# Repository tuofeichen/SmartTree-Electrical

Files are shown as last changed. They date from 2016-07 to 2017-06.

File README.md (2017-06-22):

# SmartTree Electrical System Design 
This repo contains the PCB design and Arduino code for the SmartTree electrical system. As a part of Engineers for a Sustainable World (ESW) at Northwestern, SmartTree is a student-run design project aimed to bring solar energy to Northwestern and get the community involved in sustainability. SmartTree provides a ‘trunk’ of solar-powered AC and USB outlets centered around a seating area, so anyone can bring his or her laptop or phone outside without having to worry about running low on battery. Having SmartTree on campus will not only allow students to best utilize technology outdoors, but also raise awareness for the potential solutions clean energy can bring to everyday life. Learn more about [ESW @ NU](http://www.eswnu.org/). 

The repo's directory is briefly described as below:

### Construction Documentation
contains the overall construction and design documentation, including hardware and software overview of the system. 

### BMS Software Documentation
contains the documentation for the battery management system software. It includes the design rationale of the software and some messaging protocal we use to communicate between the BMS board and the screen board. 

### PCB 
contains the PCB design of the battery management system (BMS) and the cell monitor unit (CMU), refer to the documentation for more details. 

### SmartTree Client
contains the client code of the software. The client is the microcontroller in charge of the screen update for the UI. It receives sensor data from the server and displays it on the screen. 

### SmartTree Server
contains the server code which controls and monitors the cell monitor unit and send out the information to the client for UI. 

### Testing
contains some the testing data logged on an SD card.

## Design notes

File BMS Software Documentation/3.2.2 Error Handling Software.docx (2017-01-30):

3.2.2 Error Handling Software

The error handling code determines when the batteries are overloaded, overheated, or improperly charged, and takes corrective action to restore the system. The error handler ensures that the four measurements - temperature, input current, output current, and voltage - are within acceptable limits.

To reduce instability due to noise, the system makes multiple measurements before reacting. This is managed with an error counter for each variable. Every time a measurement is within the respective error condition, the error counter is incremented. Otherwise, the error counter is decremented until it reaches zero. When the error counter reaches an error threshold value (determined by frequency of measurement), the error flag is set and corrective action is taken.

To prevent rapid oscillation when values are close to the limit, the system uses hysteresis by requiring a stricter recovery condition to terminate the error. For the voltage and temperature errors only, a recovery counter is used in the same manner as the error counter to avoid spontaneous recovery due to noise.

For the current errors, a different approach is necessary because a current error will disconnect the path of the current, rendering future measurement impossible. To remedy this situation, the error handler will continually increment its recovery counter after the error has occurred. Once this counter reaches the partial recovery threshold, the system reconnects the current path, and the recovery counter continues to increment. Future cycles will measure the current, and if the value does not satisfy the recovery condition, the system will reset the counter and disconnect the circuit immediately. Otherwise, the cycle repeats until the counter reaches the full recovery threshold, which indicates that the recovery condition has been satisfied for a specified number of cycles. The error flag and recovery counter are then reset and operation continues as usual.

The following errors are recognized:

Error | Error Condition | Recovery Condition | Action
High Temperature | T > 50°C | T < 45°C | Electrically isolate battery
High Voltage | V > 43.5 V | V < 43.0 V | Stop charging
Low Voltage | V < 36.0 V | V > 36.5 V | Stop discharging
High Current In | I > 6.6 A | I < 6.1 A | Stop charging
High Current Out | I > 6.6 A | I < 6.1 A | Stop discharging

Table n

In addition, there is an undercurrent input warning, where I < 1.0 A. This warning does not require a counter or a recovery value for hysteresis, since the warning takes no action except for displaying a warning on the screen. (Requires rationale for undercurrent input warning, trickle charging bad?)

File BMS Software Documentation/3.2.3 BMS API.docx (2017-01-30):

3.2.3 Battery Management System API

Header File: bmucell.h

Implementation: bmucell.cpp

Public Methods

static Cell::setup()

Configures pins used by all Cells. Must be called before all methods except the constructor.

Cell::Cell(unsigned int cellNumber)

Constructs a Cell and configures pins used by the specific Cell indicated by cellNumber. The mapping of cellNumber to the required pins and the data acquisition procedure is implementation specific.

void Cell::update()

Updates all measurements for the specific Cell. Does not identify or handle error conditions.

bool Cell::checkErrors()

Identifies and handles error conditions for the specific Cell. This method should be called soon after Cell::update() is called, in order to use the most recent measurements.

The return value is true if an error condition is detected.

void Cell::logData(Stream& stream)

Logs the measurements (temperature, voltage, current in, and current out) to a specified Stream.

void Cell::logErrors(Stream& stream, bool verbose)

Logs the error condition to a specified Stream. If verbose is true, then the errors will be displayed in English; otherwise the error conditions will be logged hexidecimal form. A lookup table to determine error conditions is in Appendix n.

double Cell::getTemperature()

Gets the most recently read temperature, in degrees Celsius.

double Cell::getVoltage()

Gets the most recently read voltage, in volts.

double Cell::getCurrentIn()

Gets the most recently current entering the cell, in amperes. Note that this value is considered invalid when error conditions prevent charging, but in practice will be close to zero.

double Cell::getCurrentOut()

Gets the most recently current exiting the cell, in amperes. Note that this value is considered invalid when error conditions prevent discharging, but in practice will be close to zero.

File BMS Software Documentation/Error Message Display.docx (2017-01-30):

Errors higher on the list are displayed with higher priority than lower errors.

Error | Cells affected | Display | Message
Temperature | 4 | Large box | Our batteries are overheating! We cannot charge your device. Sorry for the inconvenience.
Undervoltage | 4 | Large box | Low battery. We cannot charge your device. Sorry for the inconvenience.
Temperature | 1-3 | Large box | Our batteries are overheating! Charging is not recommended. Sorry for the inconvenience.
Overcurrent out | 3-4 | Large box | The Smart Tree is xxx% overloaded. Please unplug all devices. Normal operation is expected to resume shortly.
Overcurrent out | 1-2 | Large box | The Smart Tree is xx% overloaded. Please unplug large devices such as laptop chargers. Normal operation is expected to resume shortly.
Undervoltage | 1-3 | Small box | Operating at x/4 capacity due to low voltage.
Charging errors* | 1-4 | Small box | x/4 cells have stopped charging.

*Charging errors include overvoltage and overcurrent input errors, which prevent charging a cell. Each cell that cannot charge due to either error is counted as affected. Temperature errors are not included because they trigger higher priority error messages.

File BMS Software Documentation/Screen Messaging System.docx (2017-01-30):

Smart Tree Screen Message System

1. Message from BMS to screen

The syntax of a message is as follows:

<action character>:

<number of arguments>

<argument 1>

<argument 2>

…

<argument n>

;

All arguments, including numeric arguments, are in ASCII textual form.

The following action types are recognized.

Action | Char | # Args | Description of Arguments
update energy Bars | B | 0-8 | The arguments represent the height of each bar. The plot’s y-axis scale is automatically calculated by the values. Note that writing to the energy bars does not erase the bars that are not written to; e.g. if the number of arguments is 5, then bar 7 is not erased.
Clear notice area | C | 0
update screen Data | D | 3 | The arguments are, in the following order: power in, energy, power out. (need to add total energy)
display Error message✝ | E | 1+ | Each argument is a line of text to be displayed on top of the error popup window.
display built-in error message* | e | 1-2 | The first argument is the error number. The second argument, if present, is a parameter of the error message. Some error messages have a parameter (e.g. n/4 batteries have stopped charging).
Log data | L | 2 | The first argument is the file name, and the second argument is a line of data to log.
update battery Meter | M | 1 | The argument is the percent charge of the batteries.
display Notice message*✝ | N | 1+ | Each argument is a line of the notice (minor error) message.
display built-in notice message* | | | The first argument is the error number. The second argument, if present, is a parameter of the notice message. Some notice messages have a parameter.
Refresh normal screen | R | 0
Turn screen off (Sleep) | S | 0
Turn screen on (Wake) | W | 0

*These actions are not completely implemented.

✝These actions are deprecated.

To add or remove an action, the second argument to the Receiver constructor must be modified. Characters included in the string are recognized actions, all others will cause a Fail response to be sent back to the transmitter. Note that the characters do not have to be in any particular order in the accepted actions string. The current constructor is the following.

Receiver r(Serial1, "BCDEeLMNnRSW");

2. Response from screen to BMS

Important: Currently, the BMS does not monitor the responses. However, responses are sent by the screen for future use, and can provide useful information to the BMS regarding screen state.

The response from the screen to the BMS takes the form of a single character. The following responses are currently defined:

Response | Character | Description
REPLY_SUCCESS | S | The screen has successfully parsed a message.
REPLY_BUSY | B | The screen is currently processing a message.
REPLY_READY | R | The screen is ready for another message.
REPLY_FAILED | F | The screen either: - Could not successfully parse the message; - Did not recognize the requested action; or - Determined that the arguments were invalid.

Recommended future behavior of the BMS include:

- Stop sending a message immediately upon fail;
- Try to resend a message upon fail;
- Log failed transmissions in a separate file; and
- Delay sending if REPLY_BUSY has been received.

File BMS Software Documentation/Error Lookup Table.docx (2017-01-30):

Error Lookup Table

First Character | | | Second Character
Err. Code | Overcurrent Out | Undercurrent In (warning) | Err. Code | Temp. | Overvoltage | Undervoltage | Overcurrent In
0 | | | 0
1 | ✓ | | 1 | ✓
2 | | ✓ | 2 | | ✓
3 | ✓ | ✓ | 3 | ✓ | ✓
| | | 4 | | | ✓
| | | 5 | ✓ | | ✓
| | | 6 | | ✓ | ✓
| | | 7 | ✓ | ✓ | ✓
| | | 8 | | | | ✓
| | | 9 | ✓ | | | ✓
| | | a | | ✓ | | ✓
| | | b | ✓ | ✓ | | ✓
| | | c | | | ✓ | ✓
| | | b | ✓ | | ✓ | ✓
| | | e | | ✓ | ✓ | ✓
| | | f | ✓ | ✓ | ✓ | ✓

#define TEMP_ERROR_H 1

#define UNDERVOLTAGE_ERROR_H 2

#define TEMP_ERROR_L 3

#define OVERCURRENT_OUT_ERROR_H 4

#define OVERCURRENT_OUT_ERROR_L 5

#define UNDERVOLTAGE_ERROR_L 6

#define CHARGE_ERROR 7

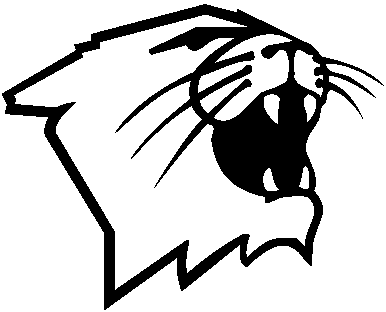
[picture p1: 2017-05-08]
PCB/wildbw.bmp

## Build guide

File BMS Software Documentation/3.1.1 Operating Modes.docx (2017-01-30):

3.1.1 Operating Modes

The Smart Tree can operate in four modes: Normal, Error, Sleep, and Debug. The Normal mode represents daytime operation without errors. The Error mode represents when at least one cell has detected an error condition; in this mode an error is displayed on the screen. The Sleep mode is entered at night; the screen is turned off in this mode. The Debug mode can be activated by a technician to debug or change settings in the Smart Tree.

Instead of representing these 4 modes with a minimal 4 states, we use 3 flags: Debug, Sleep, and Error. Each of these flags is always kept updated, whether it has an immediate effect on the system or not. This way, after debug or sleep is turned off, the proper state can be restored immediately. Internally there are 8 states, but the end result is the original four operating modes.

Flags | | | Mode | Indicators
Debug | Sleep | Error | | LED1 | LED2
0 | 0 | 0 | Normal mode: displays energy and power | 0 | 0
0 | 0 | 1 | Error mode: displays error | 0 | 1
0 | 1 | X | Sleep mode; display turned off | 1 | 0
1 | X | X | Debug mode | 1 | 1

The don’t-care flags will continually be updated by the BMS and sleep timer interrupts during the sleep or debug modes, so when they exit, its respective flag can simply be cleared and operation can resume immediately in the proper state, without requiring additional measurements.

Rationale

The rationale for this slightly more complicated model is because of the decision making required when exiting the sleep and debug states. Exiting the sleep mode requires analysis of the error status of each cell to enter the correct mode; exiting the debug state requires analysis of both the sleep timer and the error status. To minimize bugs and maximize performance, it is preferable to perform this analysis in one location of the code, controlled by the interrupts as in normal operation. In addition, it is preferable to perform this analysis in constant intervals of time, to facilitate calculation of energy and power. We solve both of these issues by saving the sleep and error flags even when they do not affect the current mode, so that the proper mode to enter is already determined upon exit.

Error mode (requires a error message)

1. undervoltage for any output
2. overcurrent for any output
3. overtemperature for any output

Error mode: still whenever there’s an error

1. undervoltage
  a. if not all of them are undervoltage, draw small box, clear with a rectangle
  b. if all of them are undervoltage draw large box, redraw screen
2. overcurrent
  a. large box warning
  b. redraw screen
3. overtemperature:
  a. large box warning
  b. redraw screen

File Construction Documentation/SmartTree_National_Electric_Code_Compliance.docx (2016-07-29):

SmartTree National Electric Code Compliance Report

Introduction

This document is intended to discuss the code compliance of the SmartTree electrical system in the context of meeting the National Electric Code (NEC). Specifically, this report will give a brief overview of the specification of the system (more about the detailed design please refer to the SmartTree Electrical System Design Documentation) and address the compliance status for the three relevant NEC Articles: Article 720 Circuits and Equipment Operating at Less than 50 Volts, Article 480 Storage Batteries, and Article 720 Solar Photovoltaic Systems. Article 690 and 480 will have an entry wise discussion; Article 720 will only address the applicable part to the system.

System Specification

As shown in the point to point schematic, the 8 solar panels are split up into 4 pairs. Each pair is charging a 36v battery pack, which consists of three 12V lead acid batteries. The four battery packs all connect to a terminal block (hence in parallel) before delivering current to the inverter. This PV system is a stand-alone system as defined by the NEC.

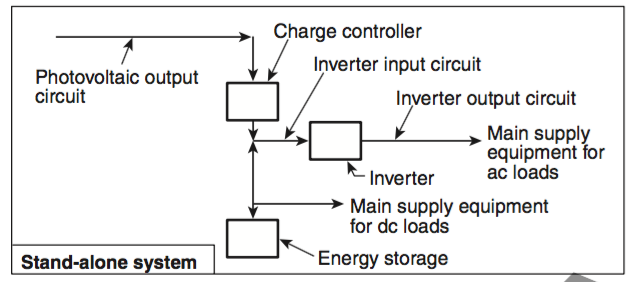
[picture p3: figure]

Figure 1 NEC defined stand-alone system

In the table below, PV Output Voltage and Current refers to the voltage and current of each pair of solar panels. Battery output voltage is 36V due to the parallel connection, and the battery output current is the sum of current from the 4 packs.

| Nominal | Maximum (w/ temperature correction)
PV Output Voltage (BP 275)¹ | 34.0 V | 45.42 V
PV Output Current (BP 275) | 4.45 A | 4.65 A
PV Output Power (BP 275) | 70 W | 75 W
PV Output Voltage (VLS 85) | 36 V | 50.29 V
PV Output Current (VLS 85) | 4.72 A | 5.00 A
PV Output Power (VLS 85) | - | 85 W
MPPT Input voltage | 36V | 63 V
MPPT Input Current | 8 A | -
MPPT Output Voltage | - | 43.2 V
Battery Input Voltage | 43.2 V | 45 V
Battery Input Current | - | 6.6A @ 0.3C
Battery Output Voltage | 36 V | 40 V
Total Battery Output Current | 8.8 A @ 0.1C | 17.6 A @ 0.2C
Inverter Input Voltage | 36 V
Inverter Input Current | 8.33 A
Inverter Output Voltage | 110 V (AC) | -
Inverter Output Current | 5.46 A
Inverter Output Power | 300 W | -

Table 1 System Specification

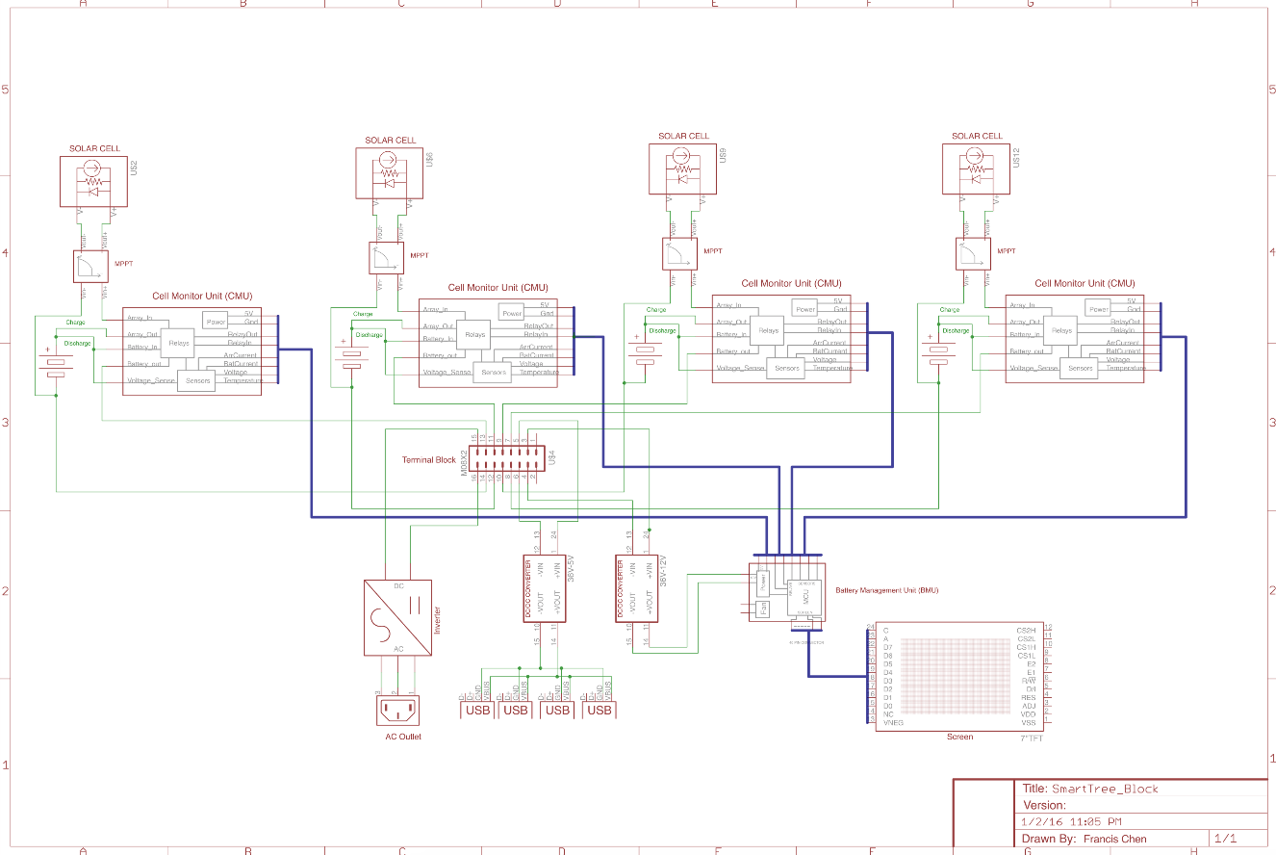
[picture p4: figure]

Figure 2* Point to Point Schematic

ARTICLE 720

Circuits and Equipment Operating at Less Than 50 Volts

[720.1 Scope] The SmartTree electrical system fit in the scope described by the NEC article 720. The highest DC voltage involved is the three serially connected 12V lead acid battery, stacking at to 36V.

[720.2 Other Articles] Other articles mentioned in NEC do not apply except Article 690, PV system, which will be discussed later.

[720.3 Hazardous Locations] System will not be installed in Class 1,2 or 3 hazardous locations.

[720.4 Conductors] All power bus conductors are rated 12 AWG or above.

[720.6-7 Receptacles] Receptacles for power bus are mainly three kinds: 2 pin Megafit Molex connector, 30Amp power pole Anderson connectors and 10-12AWG ring connectors. The Megafit can deliver 23A of current. Thus both can handle more than 15A of current.

[720.11 Mechanical Execution] All power electronics are enclosed in battery boxes where components and wirings are properly installed.

ARTICLE 480

Storage Batteries

[480.3 Cell terminations] Batteries are placed in battery boxes. Ring connectors are used to connect between different batteries and no mechanical strain is applied.

[480.6 Disconnecting Means] A switch box is in place for maintenance personnel to disconnect the battery system, in addition to the built in battery management system that implement overcurrent/under voltage protection.

[480.7 Insulation of Batteries Not Over 250 Volts] Batteries purchased for the system belong to class (D) Sealed Cells or Batteries and it doesn’t require additional insulation support.

[480.9 Battery Locations] Battery will be placed in a weatherproof battery box with ventilation. Live parts are properly mounted on the battery box.

[480.10 Vents.] Vents are available on the battery box which contains the sealed lead acid battery.

ARTICLE 690

Solar Photovoltaic (PV) Systems

I. General Requirement

SmartTree electrical system uses inverter, charge controller, and PV modules listed for PV applications, DC-DC Converters are not specified for PV application, but their input and output voltage range are within the limit of the system and the specification of the parts.

690.4(C) Qualified Personnel

The installation of equipment and all associated wiring and interconnections shall be per- formed only by qualified persons. [ROP 4–188a] Even though his is a low voltage off grid system, we still plan to have electrician present for the installation.

(690.5) As mentioned above, every circuit has only 2 parallel source circuits and all DC source and output are isolated from the structure. Thus no ground fault protection is required according to the code.

II. Circuit Requirements

690.8 Circuit Sizing and Current

1. PV Module

The maximum voltage and current of the PV module is calculated as below

Voltage:

For every pair of series BP275 PV Modules, for lowest Temperature in Chicago:

Max PV Voltage=OCV*2+C_(temperature) *(25^o C-lowest temperature^2 )

=21.4 V*2+(25-(-7.7))C*80mV/C=45.42V

For every pair of series VLS-85 PV Modules,

Max PV Voltage=OCV*2*C_(temperature) *(25^o C-lowest temperature)

=22.3 V*2*(1+(25-(-7.7))C*0.39%/C)=50.29V

Current:

Pair of BP- 275:

Max PV Current=I_(SC) *C_(temperature) *(25^o C-lowest temperature)*1.25=5.81A

Pair of VLS-85:

Max PV Current=I_(SC) *C_(temperature) *(25^o C-lowest temperature)*1.25=6.25A

2. MPPT Charge Controller

The selected charge controller is the GV-Boost 105-350W solar boost charge controller, which accepts max panel OCV of 63 V and rated current of 8 Amp. Therefore max source and output current/voltage is within input rating of the MPPT charge controller. The max DC voltage is below 1000 V and is permitted not have lamp holders and fixtures. However, the system is designed to be mounted on lamp holder like structures and won’t be accessible by general public.

3. Inverter

The selected inverter is NM300 Pure Sine Inverter. Inverter continuous output current is

300 W / 110 V*2 = 5.46 A

Inverter input current rating

300W / 36V = 8.3 A

4. DC-DC converter output current rating

According to datasheet,

36-5V DC-DC converter max current output is 3A,

36-12V DC-DC converter max current output is 8A.

5. Conductor Ampacity

Power wires are at least 12 gauge, thus more than enough to handle current of the max input and output current of the mentioned equipment

6. Sizing of module interconnect

Each parallel-connected modules had its own overcurrent protection.

690.9 Overcurrent Protection:

Active and passive overcurrent protections are both deployed. Hall effect current sensors are implemented to measure the PV output current and the battery output current. A microcontroller is used to monitor the output of the current sensor and controls two solid-state relays to disconnect the PV output and battery output circuits when overcurrent is detected. A fast reacting fuse is also implemented in case of the presence of spike or surge of power.

Current sensor has ratings roughly 2 times higher than the max output calculated in 690.8. Due to low voltage (36V) and small scale of the project, generic fuses and solid-state-relays are used as overcurrent protection device. However, all of them are consistent with the voltage current and interrupt ratings of the system.

690.10 Stand Alone System

As mentioned in the introduction, this system meets the NEC definition of a stand-alone PV system. Inverter nominal output is 300 W, which is greater than expected full load condition. The load condition includes powering two laptop chargers and most laptop chargers are below 100 W. Conductors are 12 gauge copper wires, which can handle the max current from the inverter. Backfed Circuit breakers is not used in the system. As discussed above, fuses and solid-state relay are used for overcurrent protection.

III. Disconnecting Means

690.13 Building/other structures supplied by a PV system

Due to the simplicity of this system, the only other conductors within the system are the loads that connect to the batteries. In the terminal block that 4 battery boxes join, one switch box that controls each battery is present. The 4 switches is max number of disconnection means and it will isolate the PV circuit before (include) the battery from possible loads.

690.15 Disconnection of Photovoltaic Equipment

In each battery box, one switch is used to disconnect the corresponding charging circuit from PV modules. The switches in each battery box and the switch box in the center control box is readily accessible by maintenance personnel. Labels are placed next to switches to indicate disconnection from PV modules. As four subsystems are implemented, only 4 switches are present in separate enclosures.

690.16 Fuses

The fuses on the BMU boards are separable from supply by disconnecting the input and output connector.

690.17 Disconnect Type

DC-rated enclosed switches are used for all the manual disconnection means. The disconnection means will open the + line of DC source and output circuits. The – line of the circuit will be grounded with the metal structure of the tree. The PV disconnecting means are well labeled both in the battery box and in the center control box. It’s accessible to maintenance personnel without exposing to live parts.

690.18 Installations and Service

During installation and servicing, two PV output terminals will be disconnected from the charge controller.

IV. Wiring Method

690.31 Methods Permitted

PV source circuits are installed in inaccessible locations (on the top of the tree branch) and will be connected via listed PV wires. The metal branch of the tree serve as the conduit for the PV wire until it reaches the battery box, which is also not accessible to general public. However, plastic conduit is still used for power cables between battery boxes.

PV system source and output circuits are not placed in the same junction. PV source circuits are labeled. (TODO). PV output and inverter circuits are labeled (TODO). When the battery output of the four subsystems join at the terminal block. The conductor and switch of every one of them is labeled. Within the central control box, AC and DC wires are well separated and grouped by cable ties.

UL listed PV wires are used for outdoor connection between the PV module and charge controllers. Mutli-Conductor cables are not used for the PV modules and high power components. Fine stranded cables are terminated with ring connectors or Anderson connectors Removal of module shouldn’t interrupt a grounded conductor to other PV source circuits, as PV modules should all be grounded to the metal structure of the tree.

690.32 Component Interconnections

Minimum interconnections are left open for on-site assembly, which includes the connection from array to charge controller, connection from battery banks to the terminal block, connection from inverter to the AC outlet and the connection from 5V DC-DC converter to the USB hub. All of these connections are complying with the corresponding standards in the code.

690.33 Connectors

As mentioned above, connectors for power bus are mainly three kinds: 2 pin Megafit Molex connector, 30Amp power pole Anderson connectors and 10-12AWG ring connectors. The Megafit can deliver 23A of current.

Connectors are polarized and is non interchangeable with other receptacles. Connectors are all commercially available, well-insulated power connectors that should guard against contact with live parts by person. Connectors all exceed the rating of 30 volts and the expected current of the specific terminal.

Connectors used are all latching/locking type connectors.

Molex Megafit and Anderson Powerpole are all UL listed current interruptible. The ring connector on the terminal block needs a tool to disconnect and has label (Do not disconnect under load).

V. Grounding

690.41 - 50 System Grounding

All negative terminals of solar arrays, batteries and other DC electronics are connected on a terminal bar, which is in turn grounded using a ground rod. The grounding conductor will be larger than 14 AWG. Metal frames of the solar panels will be tied to the entire metal structure, which is grounded via the foundation.

VIII Battery

690.71 Installation

System voltage is 36V and it has listed fuses and relays for overcurrent protection on the energy storage side of the system. The system is lower than 48V and most of the codes here do not apply.

690.72 Charge Control

The PV module (34V – 45V) matches the voltage of the sealed lead acid batteries (nominal 36V). A maximum power point tracker and charge controller is also applied for charging 36V devices.

690.73 Battery Interconnect

12 gauge wires and ring connectors are used to connect the 3x 12V SLA batteries together, and connect these 36v modules to the terminal block.

1 1. As shown in schematic, 2 pairs of PV are connected in series, table shown are the voltage/current after the series connection 2. Lowest Temperature data from usclimatedata.com

2 * Full resolution image also included in the package

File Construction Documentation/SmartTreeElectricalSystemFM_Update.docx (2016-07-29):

SmartTree Electrical System Design Documentation

Author: Francis Chen, Allen Tang, Kevin Tian

Co-PM, Electrical Lead

July 20th 2016

Table of Content

1. Introduction
  1.1. Usage Overview
  1.2. Block Diagram
  1.3. Physical Arrangement
  1.4. Point to Point Schematic
2. Hardware
  2.1. Solar Panel
  2.2. Maximum Power Point Tracker (MPPT)
  2.3. Battery and Battery Management System (BMS)
  2.4. DC- DC Converters (36-12V) / (36-5V)
  2.5. Inverter and USB Port
  2.6. Screen
3. Software
  3.1. Architecture
  3.2. Battery Management System
    3.2.1. Battery Management API
    3.2.2. Error Handling Software
  3.3. Screen
    3.3.1. Overview
    3.3.2. External Libraries
    3.3.3. Functions
4. Energy Generation
5. Installation
  5.1. Weather Proof and Insulation
    5.1.1. Solar Panel
    5.1.2. Battery box
  5.2. Grounding
  5.3. Lightning Protection
  5.4. Battery/Control box construction

Appendix

Appendix 1: Schematic

Appendix 2:

1. Introduction

This brief introduction is intended for illustrating the high level design. Refer to the later sections for more detailed design for each individual part.

  1.1. Usage Overview

The SmartTree is a solar powered charging station that resembles the shape of a tree and provides a unique outdoor gathering place for students without worrying about their electronic devices running out of power. The 8 solar panels will power a small off-grid system with 12 lead acid batteries for energy storage. With proper voltage conversion, the system will output 2 AC outlets and 4 USB ports, for personal electronics like laptop, tablet, phones, etc., In addition, a screen will be mounted on the trunk to display the energy generation from the sun and promote the usage of renewable energy.

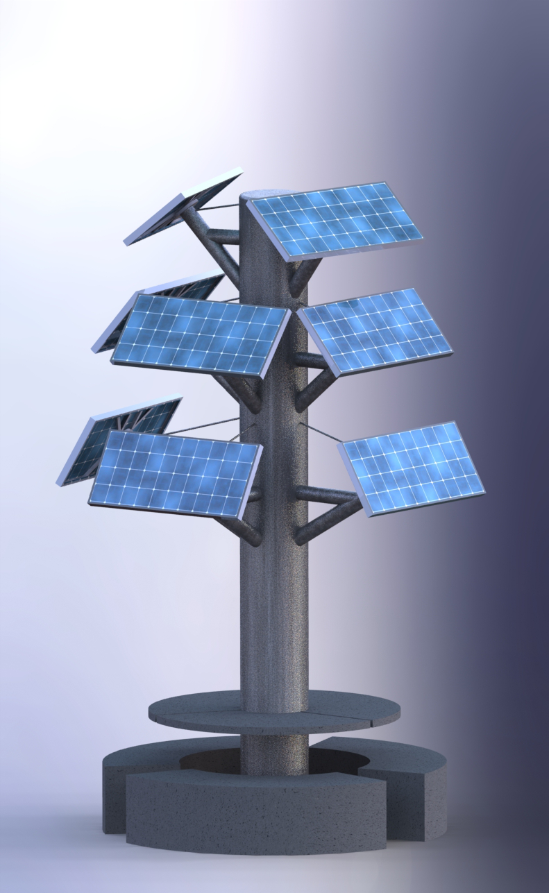
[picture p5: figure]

Figure 1.1 SmartTree CAD Model

  1.2. Block Diagram

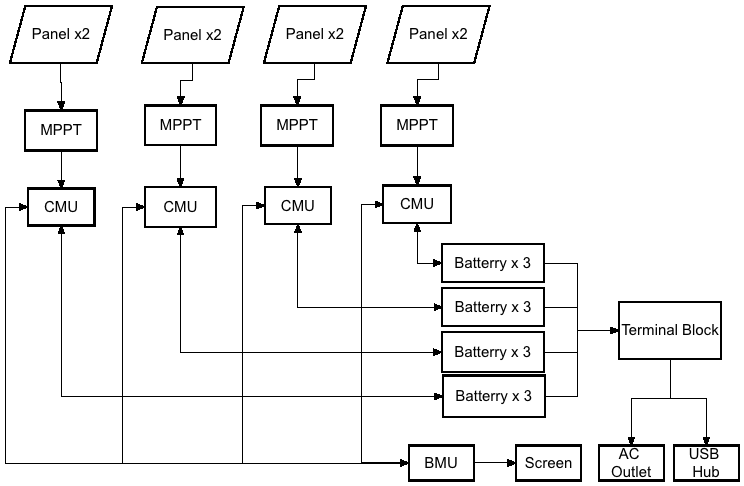
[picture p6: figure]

Figure 1.2 System Block Diagram

The overall system of the SmartTree consists of 8 solar panels, each operating at 17V/75 W max power. We paired up every two of them to form a subsystem, with three serially connected 12V lead acid batteries to store redundant energy and power the user output. Within every subsystem, a maximum power point tracker (MPPT) is implemented between the solar panels and the batteries to maximize the efficiency of the solar panel and regulate the voltage goes to the batteries. A battery management system (BMS) consists of 4 CMUs and 1 BMU is designed and implemented to monitor the state of the batteries, control the charging and discharging and displays energy savings on the screen. The four battery packs are all connected to a 36V terminal block in parallel, which in turn powers an inverter, a 36V-12V DC-DC converter and a 36V-5V DC-DC converter. The inverter will provide the AC output, the 5V will power the USB ports, and the 12V will power the electronics within the system (i.e. BMS, Screen..etc.,).

  1.3. Physical Arrangement

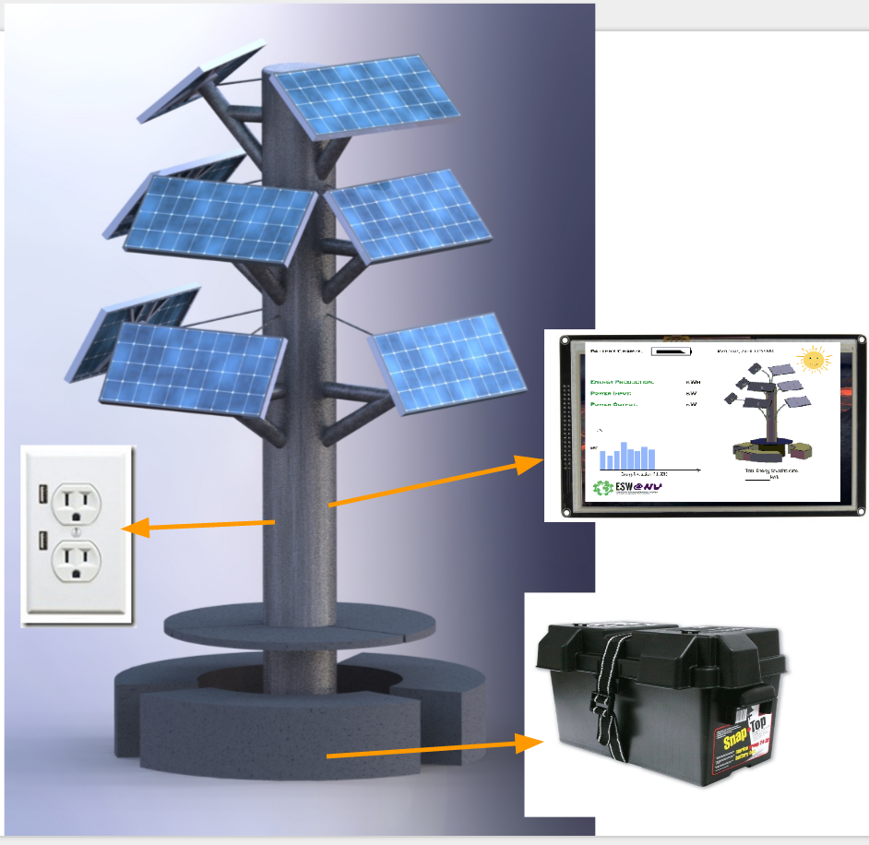
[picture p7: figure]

Figure 1.3 Physical Arrangements of Components

As shown in Figure 1.3, all the components except the solar panels, AC/USB outlets, and screen are housed within battery boxes. Solar panels are mounted at the end of the branches to collect sunlight. AC/USB outlets as well as the screen are mounted on the trunk, connecting with the battery boxes via wires running through the trunk. All the rest of the components, including battery, BMS, MPPT, inverter, DC-DC converters are all housed in five battery boxes, among which four houses batteries and one carries the control circuitry. Battery boxes are placed underground, underneath the table and benches. Individual components will be introduced in the next section.

  1.4. Point to Point Schematic

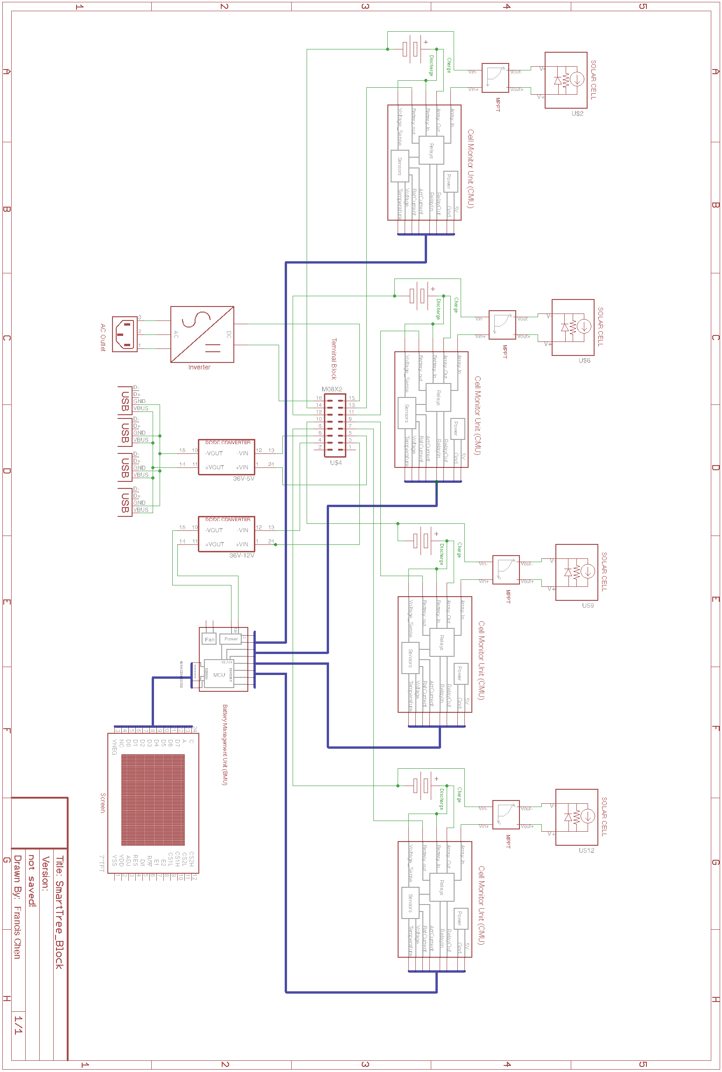
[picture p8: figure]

Figure 1.4 Point to Point Connections of SmartTree Electrical System

2. Hardware
  2.1. Solar Panel

We currently have 5 BP-275 solar panels with maximum power around 75W and 17V, and 3 VLS-85 solar panels, with maximum power around 85 W and 18V. Both models IV curve are shown below.

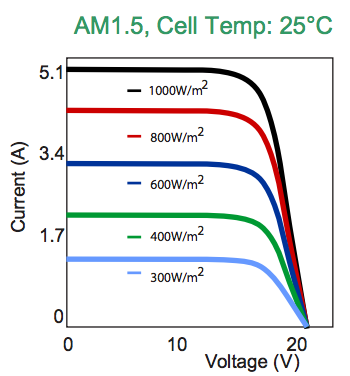
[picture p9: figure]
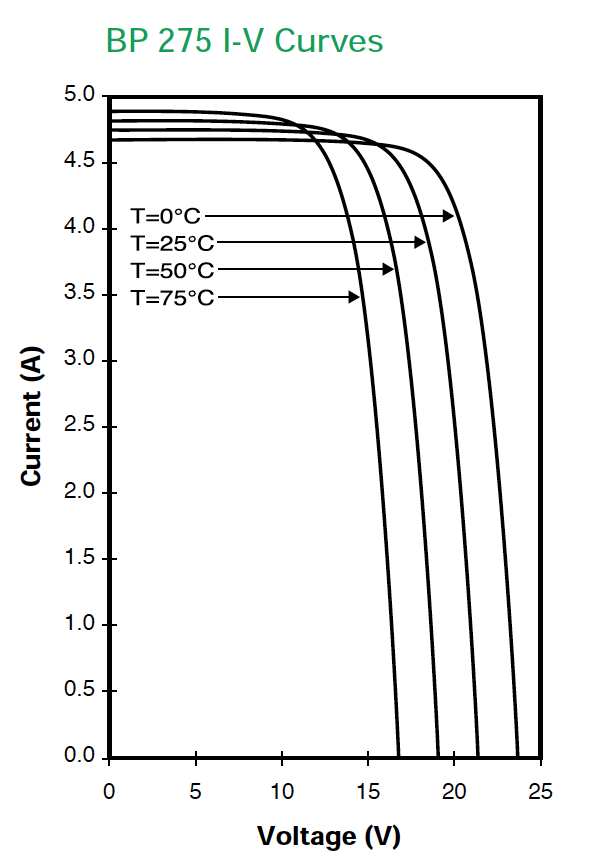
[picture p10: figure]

Figure 2.1 IV curves of solar panels (VLS-85W left, BP-275 right)

Note even though we have two different models of solar panels, the electrical and mechanical characteristics match rather well and we will be able to fit them into the system with minimal design changes.

  2.2. Maximum Power Point Tracker

Our system right now implements a Genasun GVB-8-Pb-36V MPPT, which is designed for solar golf cart that runs on 36V lead acid batteries, fitting in our application perfectly.

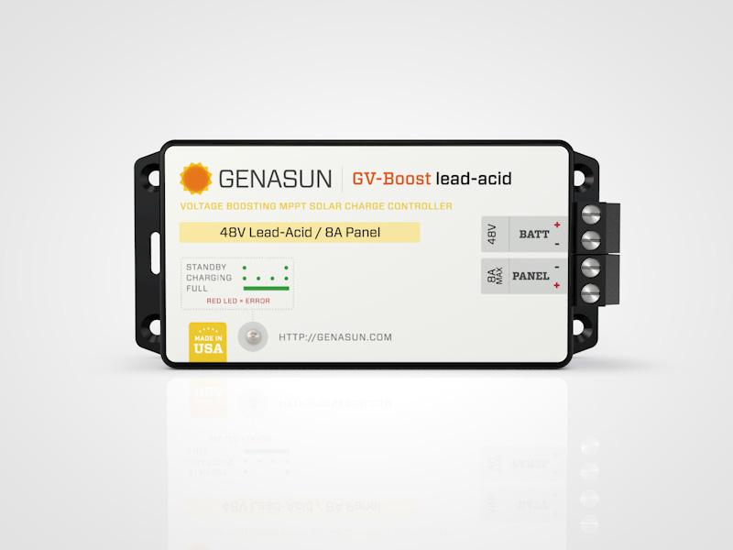
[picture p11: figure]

This commercially designed MPPT meet the specification of our panel and batteries very well and is very easy to hook up, it has been tested out with the system.

Figure 2.2 Genasun MPPT

  2.3. Battery and Battery Management System

As briefly discussed in the introduction, we have three serially connected 12V, 20Ah lead acid batteries for each subsystem, stacking up to 36V and we have the 4 battery packs from the 4 subsystems connected in parallel stacking up the current to around 8A (@0.1C).

Separated by the subsystem, we put every 3 batteries in a battery box, resulting in 4 battery boxes and the rest of the power electronics (inverter, DC-DC..etc.,) to a central control boxes, which accepts power input from all battery boxes. Again, these 5 boxes are housed underneath the table of the SmartTree to prevent it from weathering conditions. The interactions between these boxes are illustrated as below:

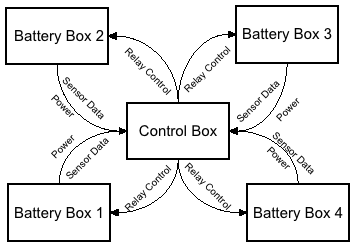
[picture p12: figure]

Figure 2.3 Battery Box Arrangements

We implemented a battery management system to monitor the power generation and the state of charge of the battery, which involves 4 Cell Monitoring Units (CMUs) and 1 Battery Management Unit (BMU).

The CMU serves two functionalities:

- Monitor state of the battery: The 4 CMUs located in the battery boxes are home designed PCBs that take the voltage, input current, output current and temperature measurement of the batteries and transmit the data to the BMU located in the control box.
- Control Charge and Discharge: The 4 CMUs accept control signals from BMU for two solid-state relays on the CMU that controls the charging and discharging process of the batteries.

The BMU serves two functionalities:

- Communicating with CMU: As mentioned above, the CMU constantly send back data to the BMU and the BMU is responsible for analyzing the voltage, current and temperature for each battery pack to decide if a fault condition has occurred and how to resolve by controlling the relays.
- Energy Calculation and Display: In addition, with the sensors data supplied by CMU, the BMU will integrate the data to get energy and power generation to display on a LCD screen for public awareness of renewable energy.

The schematic of the BMU and CMU are shown in the Appendix 1.1, essentially, BMU is a sensor aboard that has current/voltage/temperature sensors, and MOSFETs to drive relays. CMU is a microcontroller system (we’re using Arduino Due) for data processing.

  2.4. Inverter and USB Port

We bought commercially available inverter for 36V system and USB port. Specifically, we’re using the NM300 36V DC to 110V AC inverter from Nimble and a 4 outputs Amazon Basics USB Port. These commercially available products will have proper fuses and protection, adding another layer of safety.

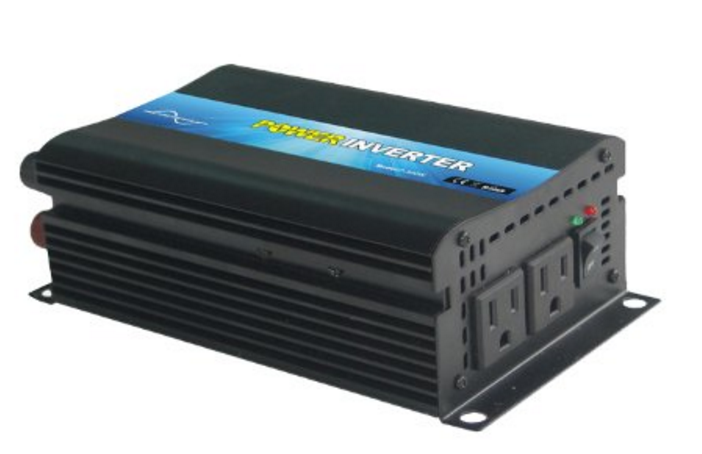
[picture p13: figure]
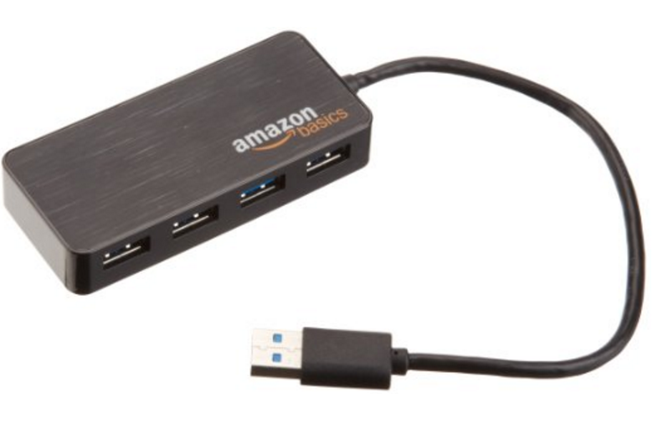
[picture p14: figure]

Figure 2.4 USB Ports and Inverter

  2.5. DC-DC Converters

A RioRand DC-DC 36V to 5V 3A Step Down Converter converter is connected to the bus bar and used to power the USB hub. A Golf Cart Voltage Reducer Converter 36v to 12v DC-DC converter is connected to the bus bar and used to power the control electronics of the system, including the relays on the BMS and the screen.

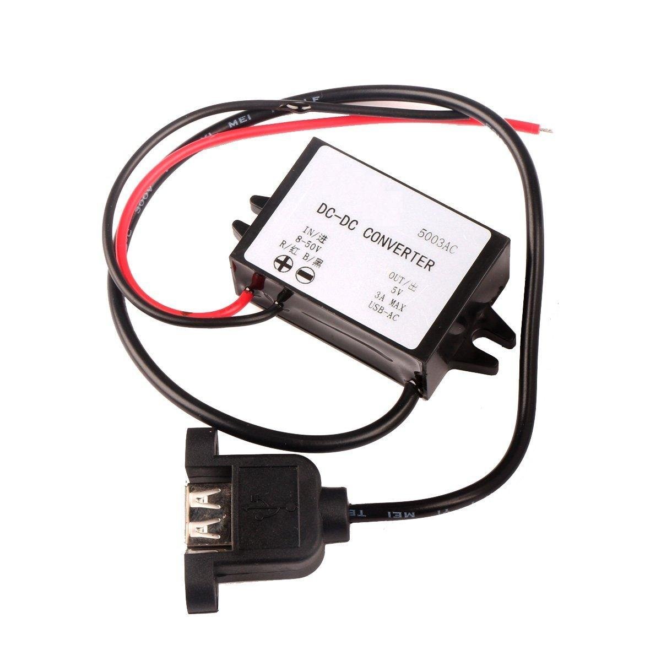
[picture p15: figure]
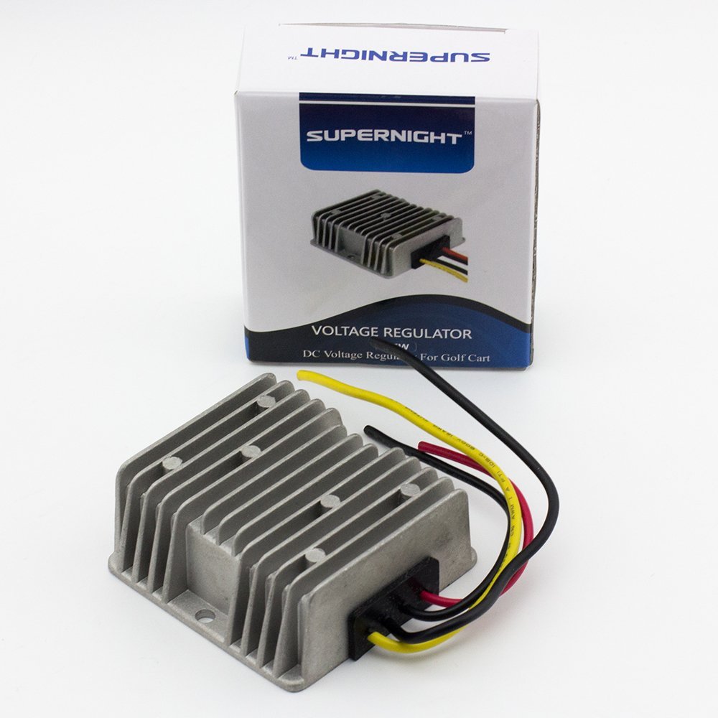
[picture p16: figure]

Figure 2.5 DC-DC Converters

  2.6. Auxiliary Power

In order to provide auxiliary power to micro-controllers in case of undesired system trip, auxiliary power is provided via an external 9 V battery pack.

  2.7. Screen

To display the power generated by the system and raise awareness of renewable energy, a

7’’ TFT screen is implemented. In this case, a 7’’ TFT from SainSmart is used which comes with pre written library and a shield fitting to the Arduino Due footprint.

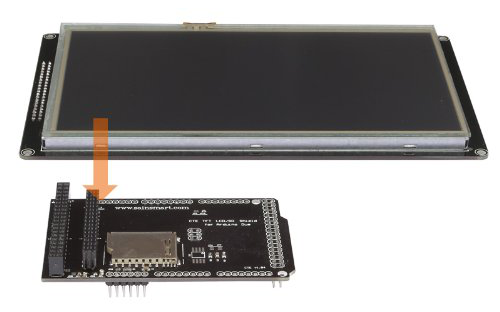
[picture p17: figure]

Figure 2.6 SainSmart 7’’ TFT for Arduinod Due

3. Software

3.2. Battery Management System (BMS)

The BMS software running on the Arduino Due reads in sensor values from the four CMUs and monitors the state of the battery packs. Its primary functionality is to ensure safety and check failure conditions, which includes, over-temperature, over-current, over-voltage and under-voltage. The detailed software documentation below is to explain the monitoring and error handling functions of the software for future reference and debugging purposes.

3.2.1. Battery Management System API

Header File: bmucell.h

Implementation: bmucell.cpp

Dependencies <arduino.h>, "pins.h"

Public Methods

static Cell::setup()

Configures pins used by all Cells. Must be called before all methods except the constructor.

Cell::Cell(unsigned int cellNumber)

Constructs a Cell and configures pins used by the specific Cell indicated by cellNumber. The mapping of cellNumber to the required pins and the data acquisition procedure is implementation specific.

void Cell::update()

Updates all measurements for the specific Cell. Does not identify or handle error conditions.

bool Cell::checkErrors()

Identifies and handles error conditions for the specific Cell. This method should be called soon after Cell::update() is called, in order to use the most recent measurements.

The return value is true if an error condition is detected.

void Cell::logData(Stream& stream)

Logs the measurements (temperature, voltage, current in, and current out) to a specified Stream.

void Cell::logErrors(Stream& stream, bool verbose)

Logs the error condition to a specified Stream. If verbose is true, then the errors will be displayed in English; otherwise the error conditions will be logged hexidecimal form. A lookup table to determine error conditions is in Appendix n.

double Cell::getTemperature()

Gets the most recently read temperature, in degrees Celsius.

double Cell::getVoltage()

Gets the most recently read voltage, in volts.

double Cell::getCurrentIn()

Gets the most recently current entering the cell, in amperes. Note that this value is considered invalid when error conditions prevent charging, but in practice will be close to zero.

double Cell::getCurrentOut()

Gets the most recently current exiting the cell, in amperes. Note that this value is considered invalid when error conditions prevent discharging, but in practice will be close to zero.

Table 3.1 Public Methods for BMS

3.2.2 Error Handling Software

The error handling code determines when the batteries are overloaded, overheated, or improperly charged, and takes corrective action to restore the system. The error handler ensures that the four measurements - temperature, input current, output current, and voltage - are within acceptable limits.

To reduce instability due to noise, the system makes multiple measurements before reacting. This is managed with an error counter for each variable. Every time a measurement is within the respective error condition, the error counter is incremented. Otherwise, the error counter is decremented until it reaches zero. When the error counter reaches an error threshold value (determined by frequency of measurement), the error flag is set and corrective action is taken.

To prevent rapid oscillation when values are close to the limit, the system uses hysteresis by requiring a stricter recovery condition to terminate the error. For the voltage and temperature errors only, a recovery counter is used in the same manner as the error counter to avoid spontaneous recovery due to noise.

For the current errors, a different approach is necessary because a current error will disconnect the path of the current, rendering future measurement impossible. To remedy this situation, the error handler will continually increment its recovery counter after the error has occurred. Once this counter reaches the partial recovery threshold, the system reconnects the current path, and the recovery counter continues to increment. Future cycles will measure the current, and if the value does not satisfy the recovery condition, the system will reset the counter and disconnect the circuit immediately. Otherwise, the cycle repeats until the counter reaches the full recovery threshold, which indicates that the recovery condition has been satisfied for a specified number of cycles. The error flag and recovery counter are then reset and operation continues as usual.

The following errors are recognized:

Error | Error Condition | Recovery Condition | Action
High Temperature | T > 50°C | T < 45°C | Electrically isolate battery
High Voltage | V > 43.5 V | V < 43.0 V | Stop charging
Low Voltage | V < 36.0 V | V > 36.5 V | Stop discharging
High Current In | I > 6.6 A | I < 6.1 A | Stop charging
High Current Out | I > 6.6 A | I < 6.1 A | Stop discharging

Table 3.2 Error Handling for BMS

In addition, there is an undercurrent input warning, where I < 1.0 A. This warninsg does not require a counter or a recovery value for hysteresis, since the warning takes no action except for displaying a warning on the screen.

Error Lookup Table

First Character | | | Second Character
Err. Code | Overcurrent Out | Undercurrent In (warning) | Err. Code | Temp. | Overvoltage | Undervoltage | Overcurrent In
0 | | | 0
1 | ✓ | | 1 | ✓
2 | | ✓ | 2 | | ✓
3 | ✓ | ✓ | 3 | ✓ | ✓
| | | 4 | | | ✓
| | | 5 | ✓ | | ✓
| | | 6 | | ✓ | ✓
| | | 7 | ✓ | ✓ | ✓
| | | 8 | | | | ✓
| | | 9 | ✓ | | | ✓
| | | a | | ✓ | | ✓
| | | b | ✓ | ✓ | | ✓
| | | c | | | ✓ | ✓
| | | b | ✓ | | ✓ | ✓
| | | e | | ✓ | ✓ | ✓
| | | f | ✓ | ✓ | ✓ | ✓

Table 3.3 Error Code generated

3.3. Screen

3.3.1 Overview

The Arduino code for the screen, “SmartTreeScreen.ino”, utilizes the pre-written libraries SPI, SdFat, UTFT, UTFT_SdRaw, rtc_clock, DueFlashStorage, efc, and flash_efc. The additional libraries coded for this project are screen and TFT.

3.3.2 External Libraries

Serial Peripheral Interface (SPI)-a synchronous serial data protocol used by microcontrollers for communicating with one or more peripheral devices quickly over short distances

SdFat-provides read/write access to FAT16/FAT32 file systems on SD/SDHC flash cards

UTFT- UTFT library for the TFT LCD screen

UTFT_SdRaw - SD card library for TFT screen

rtc_clock-real time clock for the microcontroller

DueFlashStorage-provides read/write access to the Arduino Due Flash Storage

embedded flash controller (efc)-

flash_efc

3.3.3 Functions

SDInit();

Function: Initializes the SD card in the Arduino shield

Parameters: None

LCDInit();

Function: Initializes the LCD screen and loads the image stored in the SD card

Parameters: None

RTCInit();

Function: Initializes the RTC clock, setting the time and date.

Parameters: None

UpdateBattery();

Function: Updates the battery display icon on the screen corresponding to the amount of energy left in the storage system.

Parameters: None

ErrorMessage(flag);

Function:

Parameters:

Returns:

UpdateEnergy(OldEnergy);

Function: Updates the energy generated daily in the graph on the screen display

Parameters: OldEnergy: Daily energy generated by the system

UpdateMemory(OldEnergy);

Function: Saves the daily energy generated value in Arduino Due Flash Storage

Parameters:

OldEnergy: Daily energy generated by the system

DisplayEnergy(PowerIn, OldEnergy, PowerOut);

Function: Calculates the energy generated since the last interrupt and displays the cumulative energy generated in the current day, the current power input, the current power output, and the total energy generated since initialization.

Parameters:

1. PowerIn: Current power inputted into the battery system from the solar panels
2. OldEnergy: Daily energy generated by the system
3. PowerOut: Current power being withdrawn from the battery system

Returns: Updated daily energy generated by the system Usage: OldEnergy=DisplayEnergy(PowerIn, OldEnergy, PowerOut);

datalog(PowerIn, PowerOut, OldEnergy, VoltageIn, CurrentIn);

Function: Stores the system data into an SD file with a time and date stamp

Parameters:

1. PowerIn: Current power inputted into the battery system from the solar panels
2. PowerOut: Current power being withdrawn from the battery system
3. OldEnergy: Daily energy generated by the system
4. VoltageIn: Input voltage into the battery system
5. CurrentIn: Input current into the battery system

GetDay();

Function: Retrieves the current day from the RTC clock

Parameters: None

Returns: The current day of the month

Usage: NewDay=GetDay();

ScreenInit();

Function: Initializes all the components of the screen

Parameters: None

ScreenUpdate();

Function: Updates the battery level icon on the screen

Parameters: None

DataRetrieve(VoltageIn, CurrentIn);

Function: Calculates the power input and output and the energy generated, updates the display and stores the data into the SD card.

Parameters:

1. VoltageIn: Input voltage into the battery system
2. CurrentIn: Input current into the battery system

DailyUpdate();

Function: Updates the energy generated graph and resets the daily energy value at the start of a new day

Parameters: None

4. Energy Calculation

In order to calculate the energy consumption and generation, we make assumptions to the load condition as below:

- 4 USB charging port, operating @ 5V and 1.5A (assuming Dedicated Charging Port (DCP))

- 2 Laptop consuming 100 W of power each

- Inverter operates at 70% efficiency

- Assume usage only occurs during daylight

I. Assume Nominal Operating Condition:

Nominal Output of Solar Panels= 75 W*8=600 W

Max Power of USB= 1.5A*5V*4 Hub=30 W

Max Power of Inverter=(200W)/0.7=260 W

Max Power of LCD= 5V*2A= 10 W

Max Power Consumption=30W+260W+10 W=300 W

Therefore, at any given time, power input is greater than power output.

II. Assume cloudy weather when solar cell is outputting 1/3 of its power.

Battery Capacity=36V*26Ah*4=3744 Wh

Output of Solar Panels= 75 W*8 /3=200 W

Time to drain battery=(3744Wh)/((300-200)W)=37.4 hours

Assume 8 hours of daylight, the trees can be operated with 1/3 efficiency for roughly 5 days.

III. Time to charge up the battery pack

Time to charge up=(3744Wh)/((600-300)W)= 12.48 h

Time needed to charge up battery = 3744Wh/(600-390)h = 17 hours.

Assume 8 hours of day-light, the battery back only need roughly 2 days to charge back up.

5. Installation

The installation of the electrical system requires the connection between the following components. (Picture explanation to come)

a. Solar panels to Battery Box MPPT Input - PV cable

b. Battery box battery output to control box switch box - Anderson

c. Battery box CMU signal output to control box BMU board – Ribbon cable

d. BMU board to Screen board – RS232 (DB9) cable

e. Control box 5v output to USB port on the trunk - USB extension cable.

f. Control box inverter output to AC outlet - AC extension cable

Appendix 1: Schematic of Battery Management System (BMS)

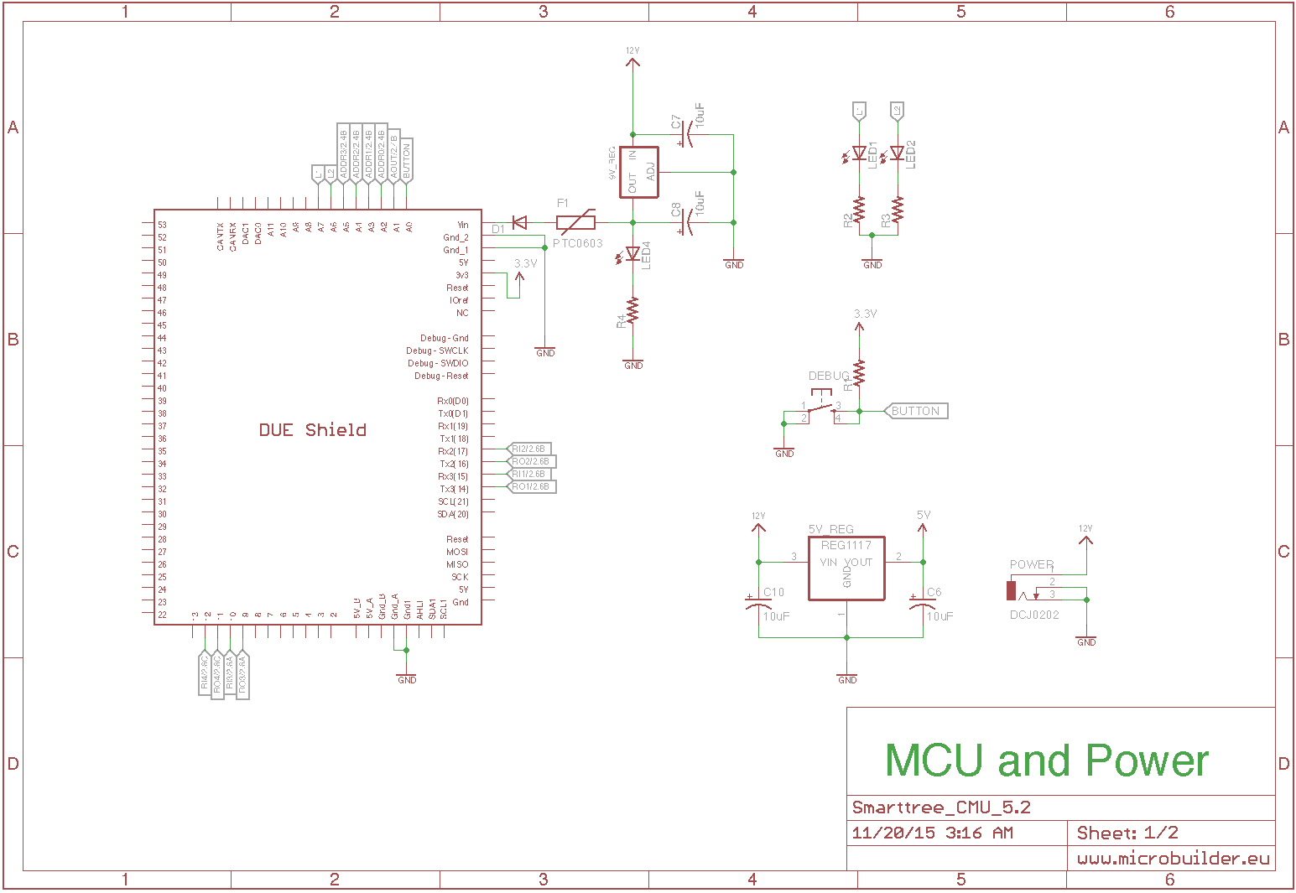
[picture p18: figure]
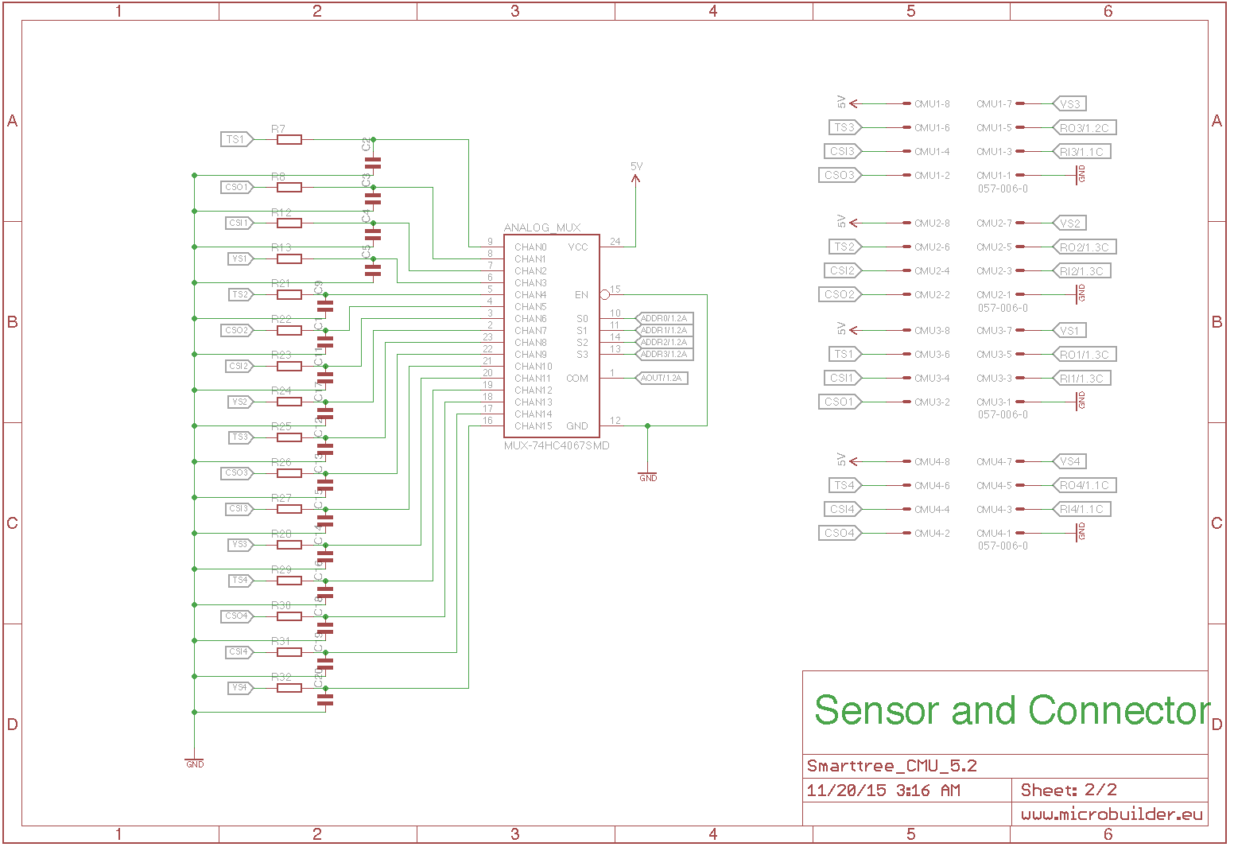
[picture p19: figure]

Schematic 1: Battery Management Unit (BMU)

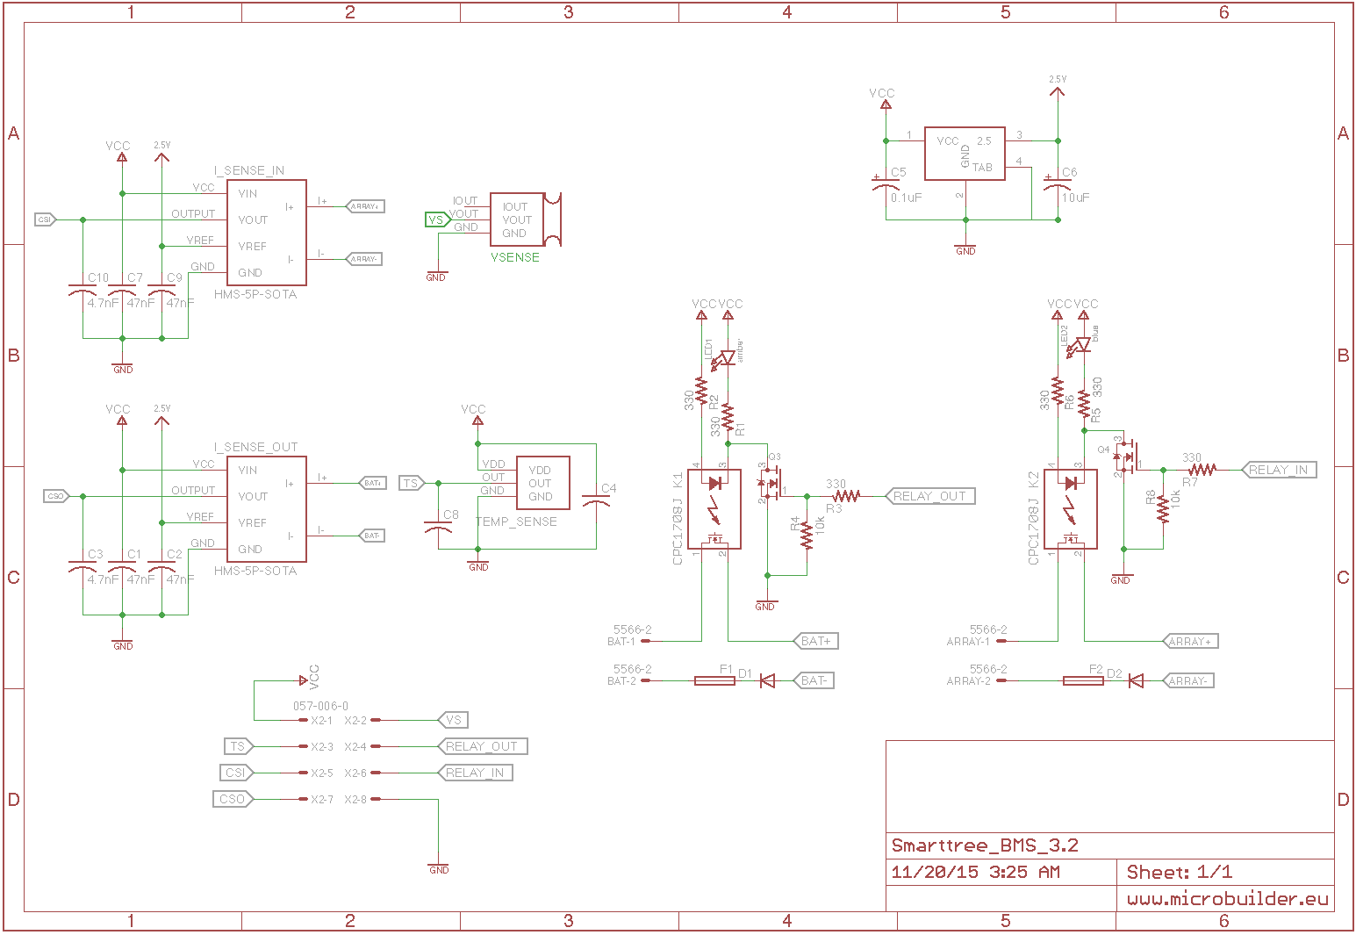
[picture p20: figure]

Schematic 2: Cell Monitoring Unit (CMU)

Tuofei Chen Engineers for a Sustainable World Tuofei.chen@gmail.com SmartTree

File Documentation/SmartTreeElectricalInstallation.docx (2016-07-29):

SmartTree Electrical System Installation Instruction

(for contractor’s reference)

Author: Francis Chen, Allen Tang, Kevin Tian

Co-PM, Electrical Lead

July 20th 2016

Table of Content

1. System Overview
  1.1. Usage Overview
  1.2. Block Diagram
  1.3. Physical Arrangement
  1.4. Point to Point Schematic
2. Installation
  2.1. Wiring
  2.2. Weather Proof and Insulation
    2.2.1. Solar Panel
    2.2.2. Battery box
    2.2.3. Wiring Raceway
    2.2.4. AC Outlet
  2.3. Grounding
1. System Overview

This brief introduction is intended for illustrating the high level design. Refer to the full Electrical System Design Documentation for more detailed design for each individual part.

  1.1. Usage Overview

The SmartTree is a solar powered charging station that resembles the shape of a tree and provides a unique outdoor gathering place for students without worrying about their electronic devices running out of power. The 8 solar panels will power a small off-grid system with 12 lead acid batteries for energy storage. With proper voltage conversion, the system will output 2 AC outlets and 4 USB ports, for personal electronics like laptop, tablet, phones, etc., In addition, a screen will be mounted on the trunk to display the energy generation from the sun and promote the usage of renewable energy.


Figure 1.1 SmartTree CAD Model

  1.2. Block Diagram


Figure 1.2 System Block Diagram

The overall system of the SmartTree consists of 8 solar panels, each operating at 17V/75 W max power. We paired up every two of them to form a subsystem, with three serially connected 12V lead acid batteries to store redundant energy and power the user output. Within every subsystem, a maximum power point tracker (MPPT) is implemented between the solar panels and the batteries to maximize the efficiency of the solar panel and regulate the voltage goes to the batteries. A battery management system (BMS) consists of 4 CMUs and 1 BMU is designed and implemented to monitor the state of the batteries, control the charging and discharging and displays energy savings on the screen. The four battery packs are all connected to a 36V terminal block in parallel, which in turn powers an inverter, a 36V-12V DC-DC converter and a 36V-5V DC-DC converter. The inverter will provide the AC output, the 5V will power the USB ports, and the 12V will power the electronics within the system (i.e. BMS, Screen..etc.,).

  1.3. Physical Arrangement


Figure 1.3 Physical Arrangements of Components

As shown in Figure 1.3, all the components except the solar panels, AC/USB outlets, and screen are housed within battery boxes. Solar panels are mounted at the end of the branches to collect sunlight. AC/USB outlets as well as the screen are mounted on the trunk, connecting with the battery boxes via wires running through the trunk. All the rest of the components, including battery, BMS, MPPT, inverter, DC-DC converters are all housed in five battery boxes, among which four houses batteries and one carries the control circuitry. Battery boxes are placed underground, underneath the table and benches. Individual components will be introduced in the next section.

  1.4. Point to Point Schematic


Figure 1.4 Point to Point Connections of SmartTree Electrical System

2. Installation

2.1. Wiring

The installation of the electrical system requires the connection between the following components. Connections are shown both in terms of schematic and the real world picture. In schematic, if other wirings are present, the connection is highlighted with red marking.

a. Solar panels to Battery Box MPPT Input - PV cable (M4 connector to Anderson)

On schematic

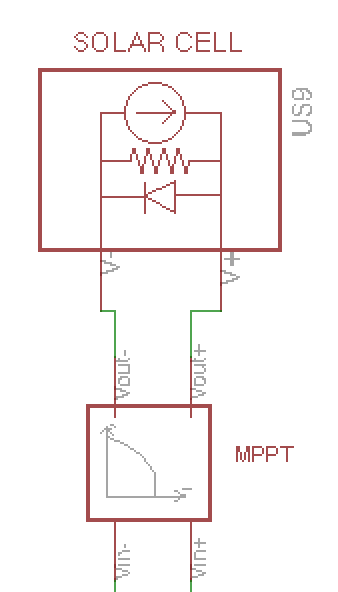
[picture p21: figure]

In Picture

[TODO: Add picture]

b. Battery box battery output to control box switch box - Anderson to Anderson

Note four of these connections should be made from four battery boxes to the central control box.

On Schematic

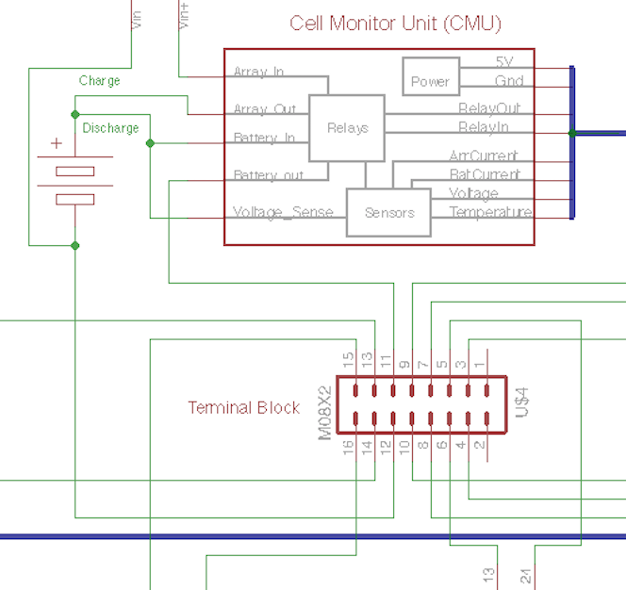
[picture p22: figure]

In Picture

[TODO: Add picture]

c. Battery box CMU signal output to control box BMU board – Ribbon cable

Similarly, four of the connections should be made. In the schematic, is the blue wire that’s denoting the bus.

On Schematic

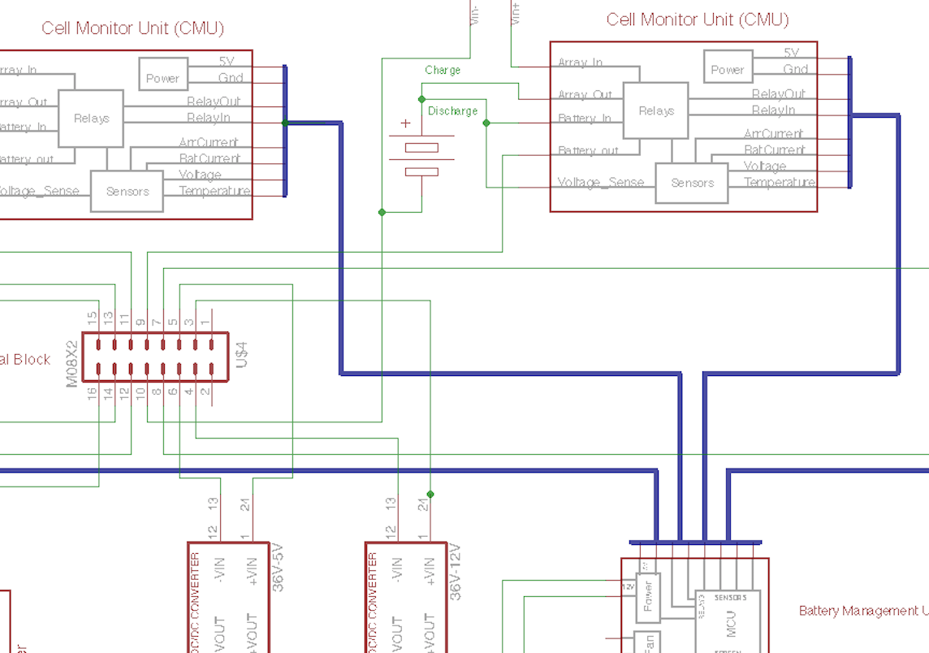
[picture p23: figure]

In Picture

[TODO: Add Pic]

d. Central Control box to screen: BMU board to Screen board – RS232 (DB9) cable

On Schematic

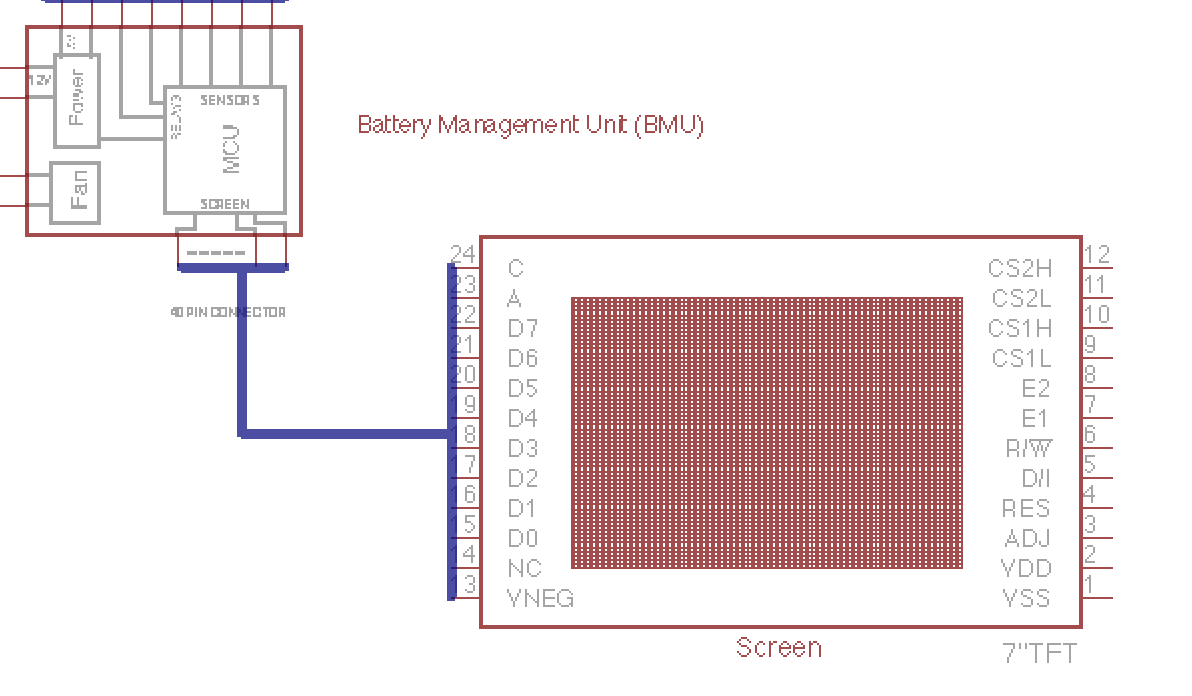
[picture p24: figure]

In Picture

e. Control box 5v output to USB port on the trunk - USB extension cable.

On Schematic

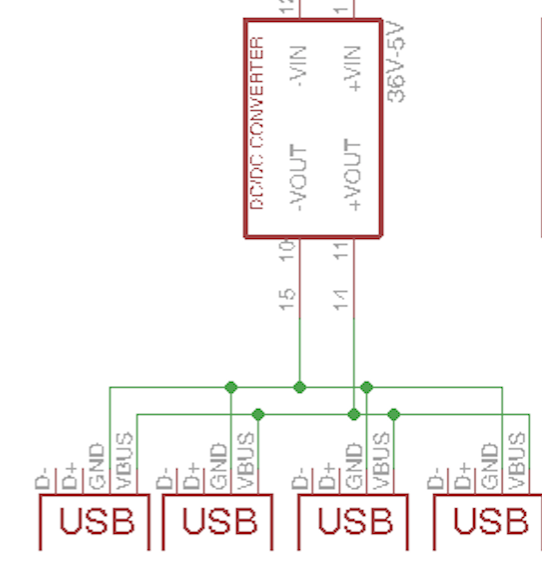
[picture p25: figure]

In Picture

f. Control box inverter output to AC outlet - AC extension cable

On Schematic

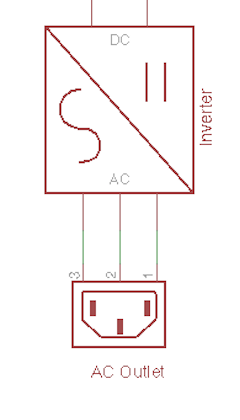
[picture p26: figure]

In Picture

2.2. Weather Proof and Insulation

2.2.1. Solar Panel Junction Box: During installation, make sure the lid of the solar panel junction box is screwed in:

[Picture]

2.2.2. Battery box: After wiring, make sure the lid of the battery box is closed:

[Picture]

2.2.3. Wiring Raceway: Wirings between battery box and control box, solar panel and battery box should be shielded with conduit.

2.2.4. AC Outlet: When installing the AC outlet, make sure the weatherproof lid is opened the right direction

[Picture]

2.3. Grounding

After finished wiring of the whole system, proper grounding can be achieved by connection the ground rod to the negative terminals of the terminal block. It tied the battery ground, charge controller ground, solar panel ground and all the power electronics ground and output device ground together and should be tied to earth ground at the very end.

[Picture ]

Tuofei Chen Engineers for a Sustainable World Tuofei.chen@gmail.com SmartTree

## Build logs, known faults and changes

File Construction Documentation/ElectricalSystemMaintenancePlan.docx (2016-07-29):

SmartTree Electrical System Maintenance Plan

Francis Chen

Electrical PM of SmartTree

Introduction

According to the agreement between Engineers for a Sustainable World (ESW)’s project team SmartTree and the Office of Facilities Management here at Northwestern University, ESW’s personnel will be responsible for maintaining the functionality and safety of the SmartTree structural and electrical system in exchange of securing the installation location every year. This following maintenance plan, along with SmartTree Electrical System Design Documentation (Design Documentation), is aimed to provide guidance for future ESW members to carry out the necessary steps for checking, troubleshooting and repairing the electrical system. This document will be continuously developed throughout construction to make it more comprehensive.

System Overview

As documented in the Design Documentation, the overall system is shown in the below schematic. We will divide up the system into the three modules as shown below and perform periodic checking on the functionality of each of the modules.

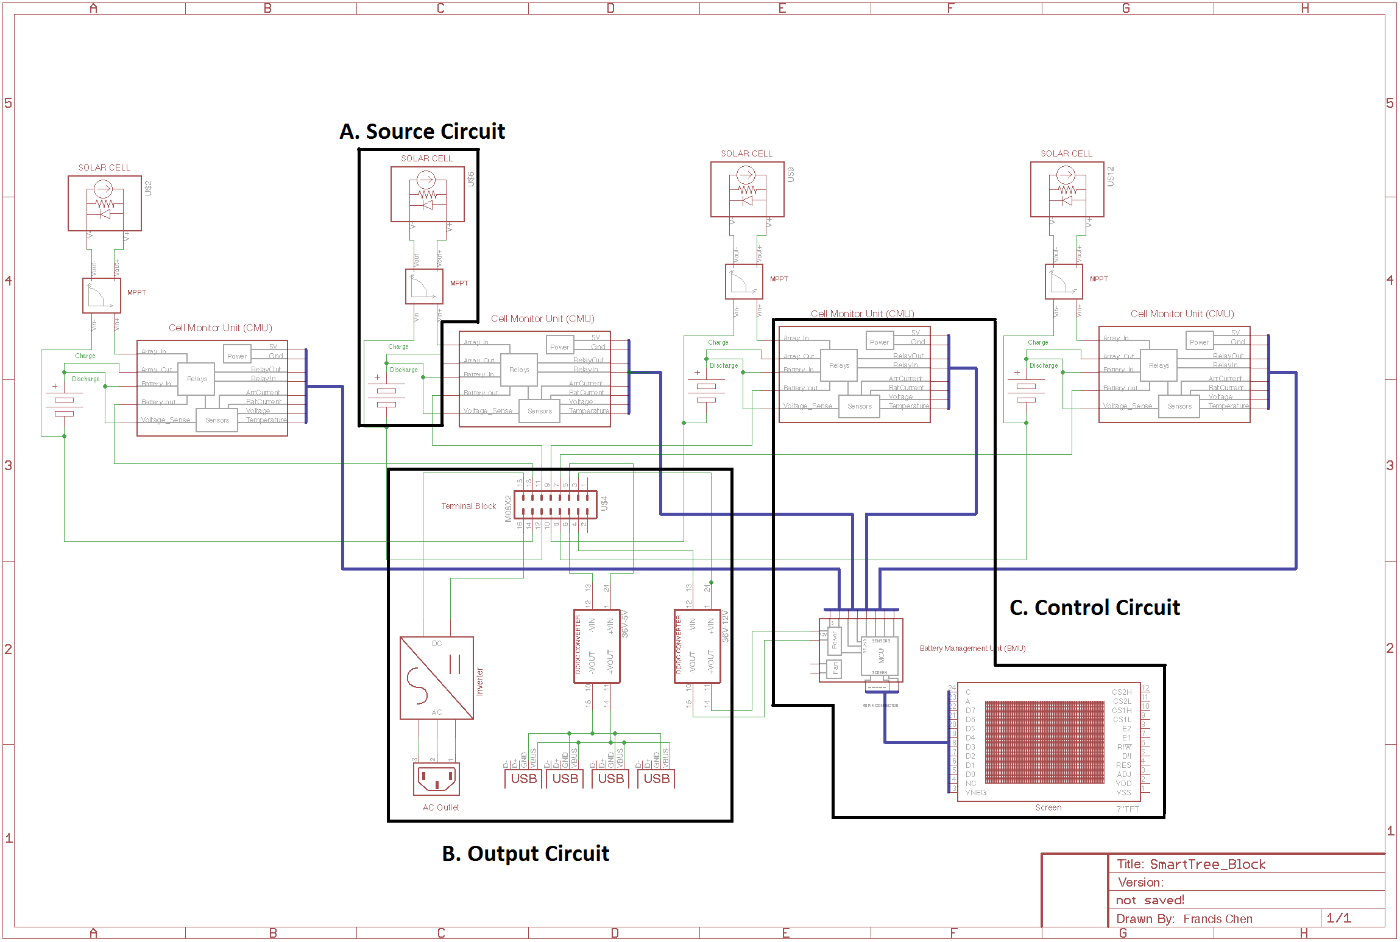
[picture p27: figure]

Figure 1. Electrical System Schematic

Maintenance Timeline

The electrical system should be checked by ESW personnel every month, in addition to after extreme weathers and/or receiving a maintenance request, on the functionality of the system,which include:

1. for source circuit: the output voltage and current of the solar panel and battery are within spec; there’s no mechanical damage to the parts (especially the solar panel); fuses are not activated.
2. for output circuit: the output voltage and current of the DC-DC converter and inverter are within spec; fuses are not activated.
3. for control circuit: the sensor measurements are consistent with the instrument measurements; the active control of the solid state relay is able to shut down the system when a fault condition occurs.

Every year, a more thorough examination of the system should take into account the following items in addition to what mentioned above:

1. Aging of the battery capacity
2. Weather proof and interconnects of the circuitry

Testing Procedure

I. Monthly Check
1. Quick Debug

For general debugging purposes, connecting the Arduino on our controller circuitry to a laptop will give out all the sensor reading of the system via serial (see below), any serial terminal program can be used as well as the Arduino serial monitor.

[Output from Serial]

In addition, datalogging is performed on an SD card every 15 seconds on the system which will provide a CSV file that maintenance personnel can use to check the overall performance of the system over the past month.

[Example Data Log]

These quick debug information will identify most of the problems within the system at a glance especially with respect to sensor failure or bad connections (short or open circuiting) or blown fuses.

2. Source Circuitry

If the problem is identified on the source circuitry side, the following measurement should be taken:

A. Output voltage of the Solar panel
B. Output voltage of the MPPT charge controller
C. Output voltage of the battery.

Any of the malfunctioning of the source circuit should be reflected on their voltage output and components will be replaced accordingly.

[Checking Source Circuit]

3. Output Circuitry

If the problem is identified on the output circuitry side, the following measurement should be taken.

A. Output voltage on the terminal bar
B. Output voltage of the 12V DC-DC Converter, this is powering all the digital circuitry of the system including sensors, datalogging, microcontroller and relays.
C. Output voltage of the 5v DC-DC Converter, this is powering the USB outlet.
D. Output voltage of the inverter and the AC outlet

If output voltage on the terminal bar is normal while there’s out-of-spec output from the power electronics as listed above, components will be replaced accordingly.

[Checking Output Circuit]

4. Control Circuitry

If the power electronics all function correctly individually, while there appear to be an open circuit / short circuit on the pathway of the power flow, it’s most likely to be a malfunction of the control circuitry.

Following checks should be performed on the control circuitry:

A. If the sensor reading from our controller is consistent with measurement using a multimeter. If not, system can be in tricked into a fault condition and cause open circuit. In this case, sensor need to be replaced.
B. If the fuses on the sensor board is connected. If not, examine the current output on each of the sensor board and replace the fuse.
C. If the relay on the sensor board is functioned correctly. If applied a voltage to the control input, the relay should close to allot current flow through. If the relayed is not functioning, replace the relay.
II. Annual Check
1. Battery Capacity: charge up the battery pack and discharge at a constant load to see if the capacity of the battery has degraded over the course of the year.
2. Interconnect: check the continuity between all the interconnects: which includes:
  a. Solar Panel to MPPT
  b. MPPT to CMU
  c. CMU to BMU
  d. 12V DC-DC converter to BMU
  e. CMU to switch box
  f. Switchbox to terminal block
  g. Terminal block to DC-DC converter
  h. Terminal block to inverter
  i. Inverter to AC Outlet

Emergency Contact

For debugging help of the system, designer of the system’s contact information is listed below.

Can Aygen: canaygen2017@u.northwestern.edu

Francis Chen: tuofeichen2017@u.northwestern.edu

Allen Tang: allentang2018@u.northwestern.edu

Kevin Tian: kevintian2018@u.northwestern.edu

Afterwards, ESW should have a dedicated team responsible for maintenance for accomplished project. Contact ESW at eswnu@gmail.com.

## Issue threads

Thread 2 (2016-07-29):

Energy bar address

tuofeichen, 2016-07-29:
Hey @kevintian18,

Can you take a look at this part ? What's this magic number 50's doing.

https://github.com/tuofeichen/SmartTree-Electrical/blob/master/SmartTree_Server/TFT.cpp#L44

kevintian18, 2016-07-30:
50 is the number of daily energy values stored in the Due flash. After 50 values are written, the energy values will wrap around and overwrite the old values. Consider making this number a global constant; either that or consider moving the data to a separate file on the SD card; that way the screen software can update the energy bars without any prompts from the BMS.

tuofeichen, 2016-07-30:
ohh i see. that's right. ok, we will see if we switch to SD card or not, but definitely gonna clean up the code there a bit. close

Closed 2016-07-30.

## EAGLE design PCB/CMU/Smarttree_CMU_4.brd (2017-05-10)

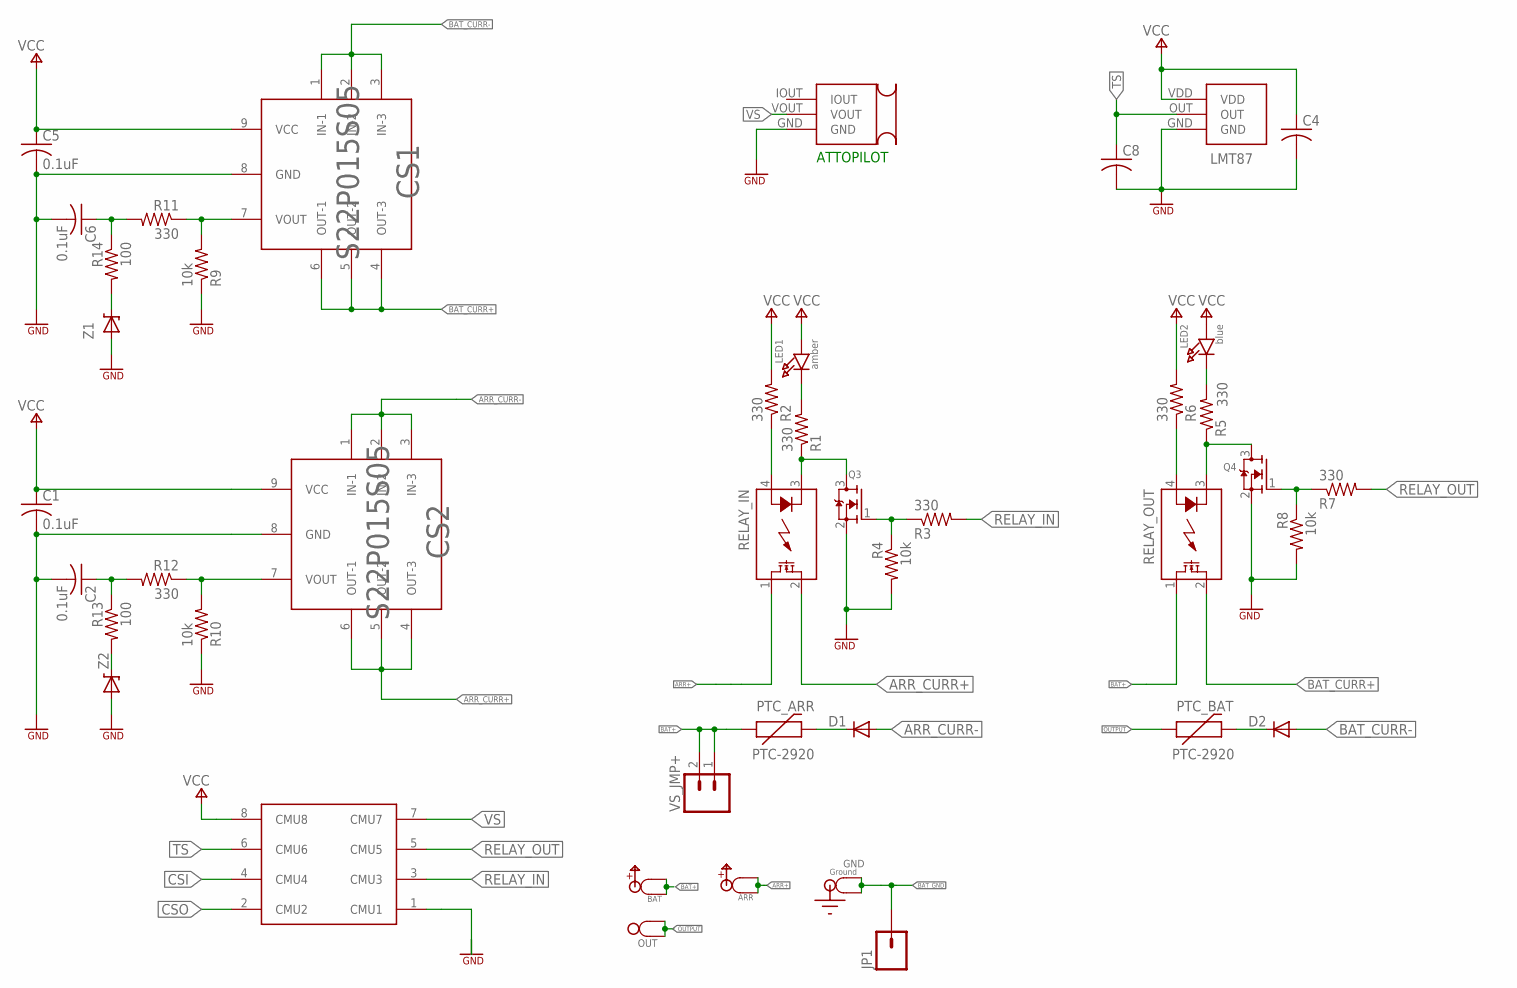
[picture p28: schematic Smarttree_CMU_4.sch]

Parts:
ARR: SPADE-POWER
ATTOPILOT: ATTOPILOT_VOLT; TH_BKOT
BAT: SPADE-POWER
C1, C2, C5, C6: 0.1uF; C0805
C4, C8: C-USC0805; C0805
CS1, CS2: S22P015S05
D1, D2: DIODE-SOD106-R; SOD106-R
GND: SPADE-GROUND
JP1: M01OFFSET; 1X01_OFFSET
LED1: amber; CHIPLED_0805
LED2: blue; CHIPLED_0805
LMT87: LMT87_PAC; LMT87_TO
OUT: SPADE-TERMINALPTH; SPADE-TERMINAL
PTC_ARR: PTC-2920
PTC_BAT: PTC-2920
Q3, Q4: MOSFET-NREFLOW; SOT23
R1, R2, R3, R5, R6, R7, R11, R12: 330; R0805
R4, R8, R9, R10: 10k; R0805
R13, R14: 100; R0805
RELAY_IN: CPC1708J; I4-PAC
RELAY_OUT: CPC1708J; I4-PAC
U$1: 8PINCONN
VS_JMP+: M02; 1X02_LONGPADS
Z1, Z2: DIODE-ZENER-BZT52; SOD-323

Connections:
ARR+: ARR.P$1, ARR.P$2, RELAY_IN.1 (DS1)
ARR_CURR+: CS2.4 (OUT-3), CS2.5 (OUT-2), CS2.6 (OUT-1), RELAY_IN.2 (DS2)
ARR_CURR-: CS2.1 (IN-1), CS2.2 (IN-2), CS2.3 (IN-3), D1.A
BAT+: BAT.P$1, BAT.P$2, PTC_ARR.1, RELAY_OUT.1 (DS1), VS_JMP+.1, VS_JMP+.2
BAT_CURR+: CS1.4 (OUT-3), CS1.5 (OUT-2), CS1.6 (OUT-1), RELAY_OUT.2 (DS2)
BAT_CURR-: CS1.1 (IN-1), CS1.2 (IN-2), CS1.3 (IN-3), D2.A
BAT_GND: GND.P$1, GND.P$2, JP1.1
CSI: C2.1, R12.2, R13.1, U$1.4 (CMU4)
CSO: C6.1, R11.2, R14.1, U$1.2 (CMU2)
GND: ATTOPILOT.GND, C1.2, C2.2, C4.2, C5.2, C6.2, C8.2, CS1.8 (GND), CS2.8 (GND), LMT87.GND, Q3.2 (S), Q4.2 (S), R4.2, R8.2, R9.1, R10.1, U$1.1 (CMU1), Z1.2 (A), Z2.2 (A)
unnamed: Q3.3 (D), R1.1, RELAY_IN.3 (K)
unnamed: Q4.3 (D), R5.1, RELAY_OUT.3 (K)
unnamed: LED1.C, R1.2
unnamed: R2.1, RELAY_IN.4 (A)
unnamed: LED2.C, R5.2
unnamed: Q3.1 (G), R3.1, R4.1
unnamed: R6.1, RELAY_OUT.4 (A)
unnamed: Q4.1 (G), R7.1, R8.1
unnamed: R13.2, Z2.1 (C)
unnamed: D2.C, PTC_BAT.2
unnamed: D1.C, PTC_ARR.2
unnamed: CS1.7 (VOUT), R9.2, R11.1
unnamed: CS2.7 (VOUT), R10.2, R12.1
unnamed: R14.2, Z1.1 (C)
OUTPUT: OUT.P$1, OUT.P$2, PTC_BAT.1
RELAY_IN: R3.2, U$1.3 (CMU3)
RELAY_OUT: R7.2, U$1.5 (CMU5)
TS: C8.1, LMT87.OUT, U$1.6 (CMU6)
VCC: C1.1, C4.1, C5.1, CS1.9 (VCC), CS2.9 (VCC), LED1.A, LED2.A, LMT87.VDD, R2.2, R6.2, U$1.8 (CMU8)
VS: ATTOPILOT.VOUT, U$1.7 (CMU7)

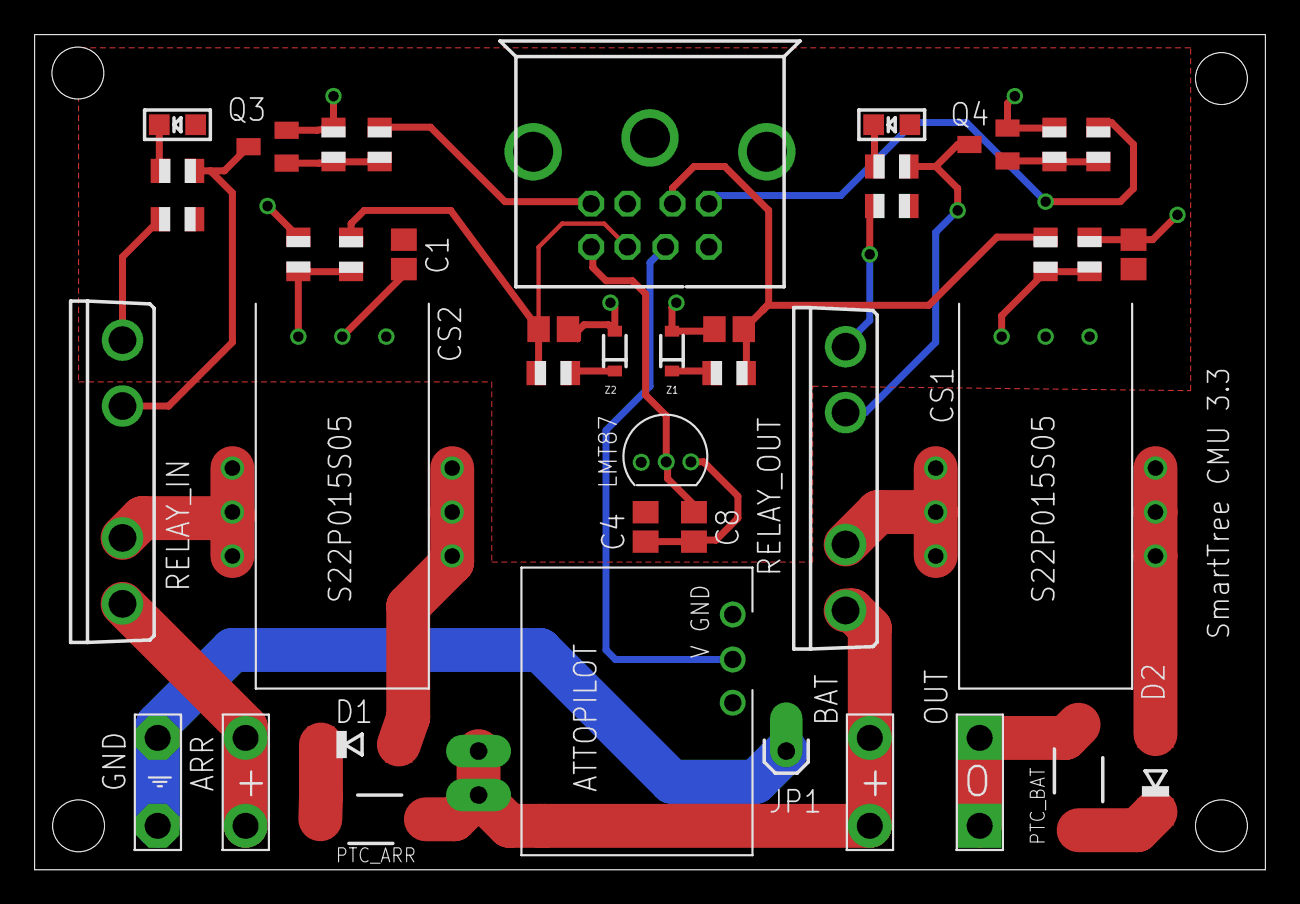
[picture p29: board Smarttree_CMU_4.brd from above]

Board: 2 copper layers, 71.1 x 48.3 mm, 43 parts (0 on the bottom side), 30 nets.

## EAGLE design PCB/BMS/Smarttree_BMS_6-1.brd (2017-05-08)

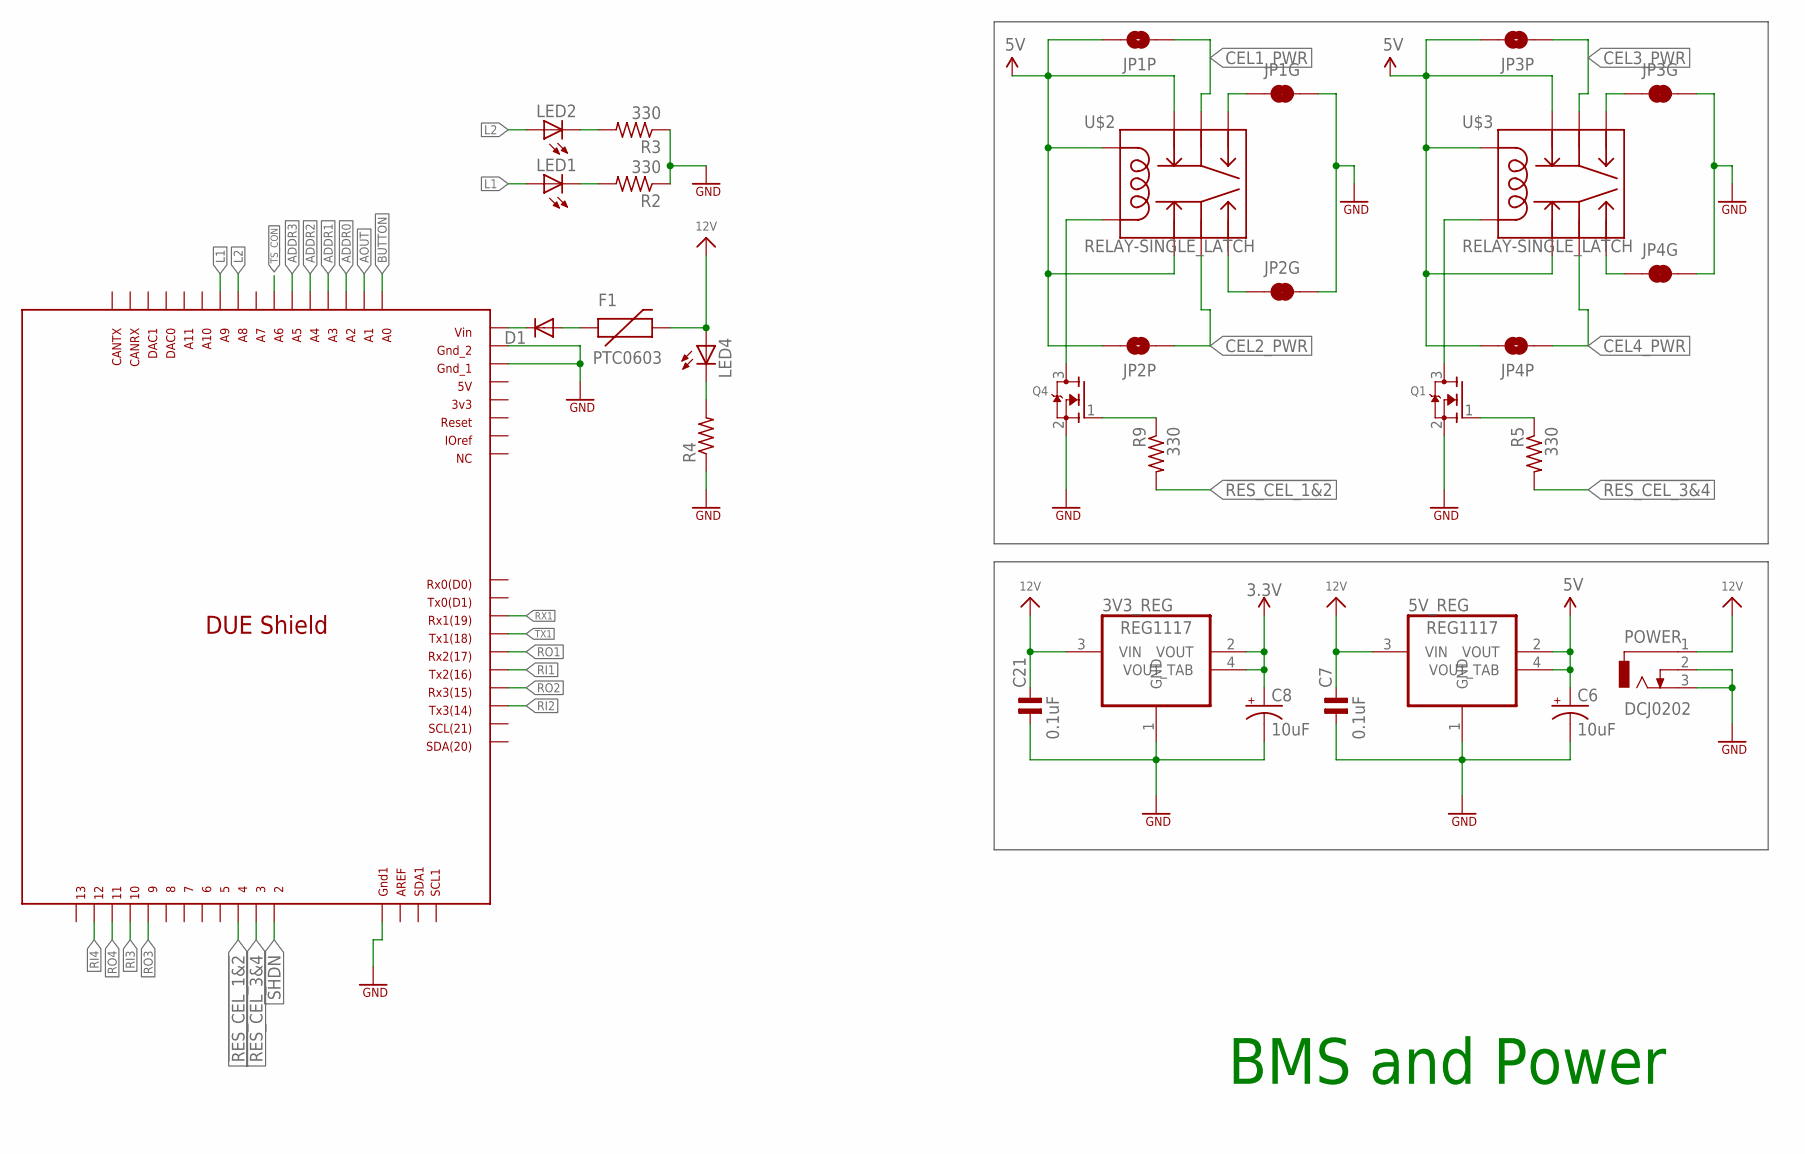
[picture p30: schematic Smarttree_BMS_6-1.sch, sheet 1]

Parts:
3V3_REG, 5V_REG: REG1117; SOT223
C6, C8: 10uF; EIA3216
C7, C21: 0.1uF; C-0805
D1: DIODE-SOD106-R; SOD106-R
F1: PTC0603; 0603
JP1G, JP2G, JP3G, JP4G: JUMPER-SMT_2_NC_TRACE_SILK; SMT-JUMPER_2_NC_TRACE_SILK
JP1P, JP2P, JP3P, JP4P: JUMPER-SMT_2_NO_SILK; SMT-JUMPER_2_NO_SILK
LED1, LED2, LED4: LED-YELLOW0603; LED-0603
POWER: DCJ0202
Q1, Q4: MOSFET-NREFLOW; SOT23
R2, R3: 330; M0805
R4: R-US_M0805; M0805
R5, R9: 330; R0805
U$1: DUE(OUTLINE); DUE(NORMAL)
U$2, U$3: RELAY-SINGLE_LATCH; RELAY-EE2

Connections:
3.3V: 3V3_REG.2 (VOUT), 3V3_REG.4 (VOUT_TAB), C8.A (+); also elsewhere on the board
5V: 5V_REG.2 (VOUT), 5V_REG.4 (VOUT_TAB), C6.A (+), JP1P.2, JP2P.2, JP3P.2, JP4P.2, U$2.P$1 (COIL1), U$2.P$3, U$2.P$10, U$3.P$1 (COIL1), U$3.P$3, U$3.P$10; also elsewhere on the board
12V: 3V3_REG.3 (VIN), 5V_REG.3 (VIN), C7.2, C21.2, F1.2, LED4.A, POWER.1; also elsewhere on the board
!RES_CEL_1&2: R9.2, U$1.4
!RES_CEL_3&4: R5.2, U$1.3
ADDR0: U$1.A2; also elsewhere on the board
ADDR1: U$1.A3; also elsewhere on the board
ADDR2: U$1.A4; also elsewhere on the board
ADDR3: U$1.A5; also elsewhere on the board
AOUT: U$1.A1; also elsewhere on the board
BUTTON: U$1.A0
CEL1_PWR: JP1P.1, U$2.P$4; also elsewhere on the board
CEL2_PWR: JP2P.1, U$2.P$9; also elsewhere on the board
CEL3_PWR: JP3P.1, U$3.P$4; also elsewhere on the board
CEL4_PWR: JP4P.1, U$3.P$9; also elsewhere on the board
GND: 3V3_REG.1 (GND), 5V_REG.1 (GND), C6.C (-), C7.1, C8.C (-), C21.1, JP1G.2, JP2G.2, JP3G.2, JP4G.2, POWER.2, POWER.3, Q1.2 (S), Q4.2 (S), R2.1, R3.1, R4.1, U$1.GND1, U$1.GND_1, U$1.GND_2; also elsewhere on the board
L1: LED1.A, U$1.A9
L2: LED2.A, U$1.A8
unnamed: JP1G.1, U$2.P$5
unnamed: Q4.3 (D), U$2.P$12 (COIL12)
unnamed: Q4.1 (G), R9.1
unnamed: Q1.1 (G), R5.1
unnamed: Q1.3 (D), U$3.P$12 (COIL12)
unnamed: JP3G.1, U$3.P$5
unnamed: JP4G.1, U$3.P$8
unnamed: D1.C, U$1.VIN
unnamed: JP2G.1, U$2.P$8
unnamed: LED1.C, R2.2
unnamed: LED2.C, R3.2
unnamed: LED4.C, R4.2
unnamed: D1.A, F1.1
RI1: U$1.TX2; also elsewhere on the board
RI2: U$1.TX3; also elsewhere on the board
RI3: U$1.10; also elsewhere on the board
RI4: U$1.12; also elsewhere on the board
RO1: U$1.RX2; also elsewhere on the board
RO2: U$1.RX3; also elsewhere on the board
RO3: U$1.9; also elsewhere on the board
RO4: U$1.11; also elsewhere on the board
RX1: U$1.RX1; also elsewhere on the board
SHDN: U$1.2; also elsewhere on the board
TS_CON: U$1.A6; also elsewhere on the board
TX1: U$1.TX1; also elsewhere on the board

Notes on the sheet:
BMS and Power

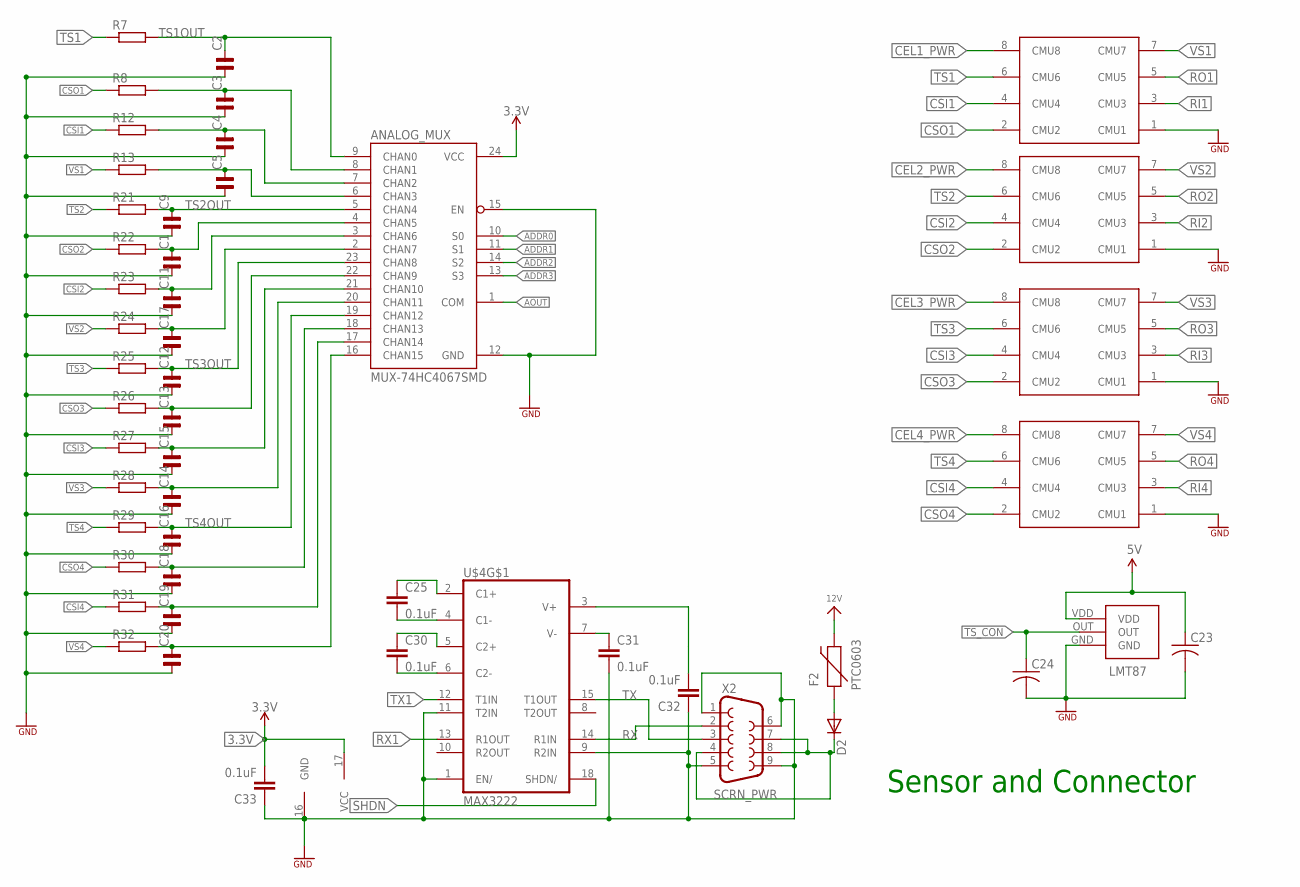
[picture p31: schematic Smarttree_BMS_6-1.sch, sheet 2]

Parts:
ANALOG_MUX: MUX-74HC4067SMD; SSOP24
C1, C2, C3, C4, C5, C9, C11, C12, C13, C14, C15, C16, C17, C18, C19, C20: C-NP-SMD-0805; C-0805
C23, C24: C-USC0805; C0805
C25, C30, C31, C32, C33: 0.1uF; 0603-CAP
CEL1, CEL2, CEL3, CEL4: 8PINCONN
D2: DIODE-SOD106-R; SOD106-R
F2: PTC0603; 0603
LMT87: LMT87_PAC; LMT87_TO
R7, R8, R12, R13, R21, R22, R23, R24, R25, R26, R27, R28, R29, R30, R31, R32: R-EU_R0805W; R0805W
U$4: MAX3222; SO18
X2: DB9MALE; DB9_MALE

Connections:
3.3V: ANALOG_MUX.24 (VCC), C33.2, U$4.17 (VCC); also elsewhere on the board
5V: C23.1, LMT87.VDD; also elsewhere on the board
12V: F2.2; also elsewhere on the board
ADDR0: ANALOG_MUX.10 (S0); also elsewhere on the board
ADDR1: ANALOG_MUX.11 (S1); also elsewhere on the board
ADDR2: ANALOG_MUX.14 (S2); also elsewhere on the board
ADDR3: ANALOG_MUX.13 (S3); also elsewhere on the board
AOUT: ANALOG_MUX.1 (COM); also elsewhere on the board
CEL1_PWR: CEL1.8 (CMU8); also elsewhere on the board
CEL2_PWR: CEL2.8 (CMU8); also elsewhere on the board
CEL3_PWR: CEL3.8 (CMU8); also elsewhere on the board
CEL4_PWR: CEL4.8 (CMU8); also elsewhere on the board
CSI1: CEL1.4 (CMU4), R12.1
CSI2: CEL2.4 (CMU4), R23.1
CSI3: CEL3.4 (CMU4), R27.1
CSI4: CEL4.4 (CMU4), R31.1
CSO1: CEL1.2 (CMU2), R8.1
CSO2: CEL2.2 (CMU2), R22.1
CSO3: CEL3.2 (CMU2), R26.1
CSO4: CEL4.2 (CMU2), R30.1
GND: ANALOG_MUX.12 (GND), ANALOG_MUX.15 (EN), C1.1, C2.1, C3.1, C4.1, C5.1, C9.1, C11.1, C12.1, C13.1, C14.1, C15.1, C16.1, C17.1, C18.1, C19.1, C20.1, C23.2, C24.2, C31.2, C32.1, C33.1, CEL1.1 (CMU1), CEL2.1 (CMU1), CEL3.1 (CMU1), CEL4.1 (CMU1), LMT87.GND, U$4.1 (EN/), U$4.9 (R2IN), U$4.11 (T2IN), U$4.16 (GND), X2.1, X2.5, X2.6, X2.9; also elsewhere on the board
unnamed: C31.1, U$4.7 (V-)
unnamed: D2.A, F2.1
unnamed: C25.1, U$4.2 (C1+)
unnamed: C25.2, U$4.4 (C1-)
unnamed: C30.1, U$4.5 (C2+)
unnamed: C30.2, U$4.6 (C2-)
unnamed: ANALOG_MUX.6 (CHAN3), C5.2, R13.2
unnamed: C32.2, U$4.3 (V+)
unnamed: ANALOG_MUX.8 (CHAN1), C3.2, R8.2
unnamed: ANALOG_MUX.7 (CHAN2), C4.2, R12.2
unnamed: ANALOG_MUX.4 (CHAN5), C1.2, R22.2
unnamed: ANALOG_MUX.3 (CHAN6), C11.2, R23.2
unnamed: ANALOG_MUX.2 (CHAN7), C17.2, R24.2
unnamed: ANALOG_MUX.22 (CHAN9), C13.2, R26.2
unnamed: ANALOG_MUX.21 (CHAN10), C15.2, R27.2
unnamed: ANALOG_MUX.20 (CHAN11), C14.2, R28.2
unnamed: ANALOG_MUX.18 (CHAN13), C18.2, R30.2
unnamed: ANALOG_MUX.17 (CHAN14), C19.2, R31.2
unnamed: ANALOG_MUX.16 (CHAN15), C20.2, R32.2
RI1: CEL1.3 (CMU3); also elsewhere on the board
RI2: CEL2.3 (CMU3); also elsewhere on the board
RI3: CEL3.3 (CMU3); also elsewhere on the board
RI4: CEL4.3 (CMU3); also elsewhere on the board
RO1: CEL1.5 (CMU5); also elsewhere on the board
RO2: CEL2.5 (CMU5); also elsewhere on the board
RO3: CEL3.5 (CMU5); also elsewhere on the board
RO4: CEL4.5 (CMU5); also elsewhere on the board
RX: U$4.14 (R1IN), X2.2
RX1: U$4.13 (R1OUT); also elsewhere on the board
SCRN_PWR: D2.C, X2.4, X2.7, X2.8
SHDN: U$4.18 (SHDN/); also elsewhere on the board
TS1: CEL1.6 (CMU6), R7.1
TS1OUT: ANALOG_MUX.9 (CHAN0), C2.2, R7.2
TS2: CEL2.6 (CMU6), R21.1
TS2OUT: ANALOG_MUX.5 (CHAN4), C9.2, R21.2
TS3: CEL3.6 (CMU6), R25.1
TS3OUT: ANALOG_MUX.23 (CHAN8), C12.2, R25.2
TS4: CEL4.6 (CMU6), R29.1
TS4OUT: ANALOG_MUX.19 (CHAN12), C16.2, R29.2
TS_CON: C24.1, LMT87.OUT; also elsewhere on the board
TX: U$4.15 (T1OUT), X2.3
TX1: U$4.12 (T1IN); also elsewhere on the board
VS1: CEL1.7 (CMU7), R13.1
VS2: CEL2.7 (CMU7), R24.1
VS3: CEL3.7 (CMU7), R28.1
VS4: CEL4.7 (CMU7), R32.1

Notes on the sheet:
Sensor and Connector

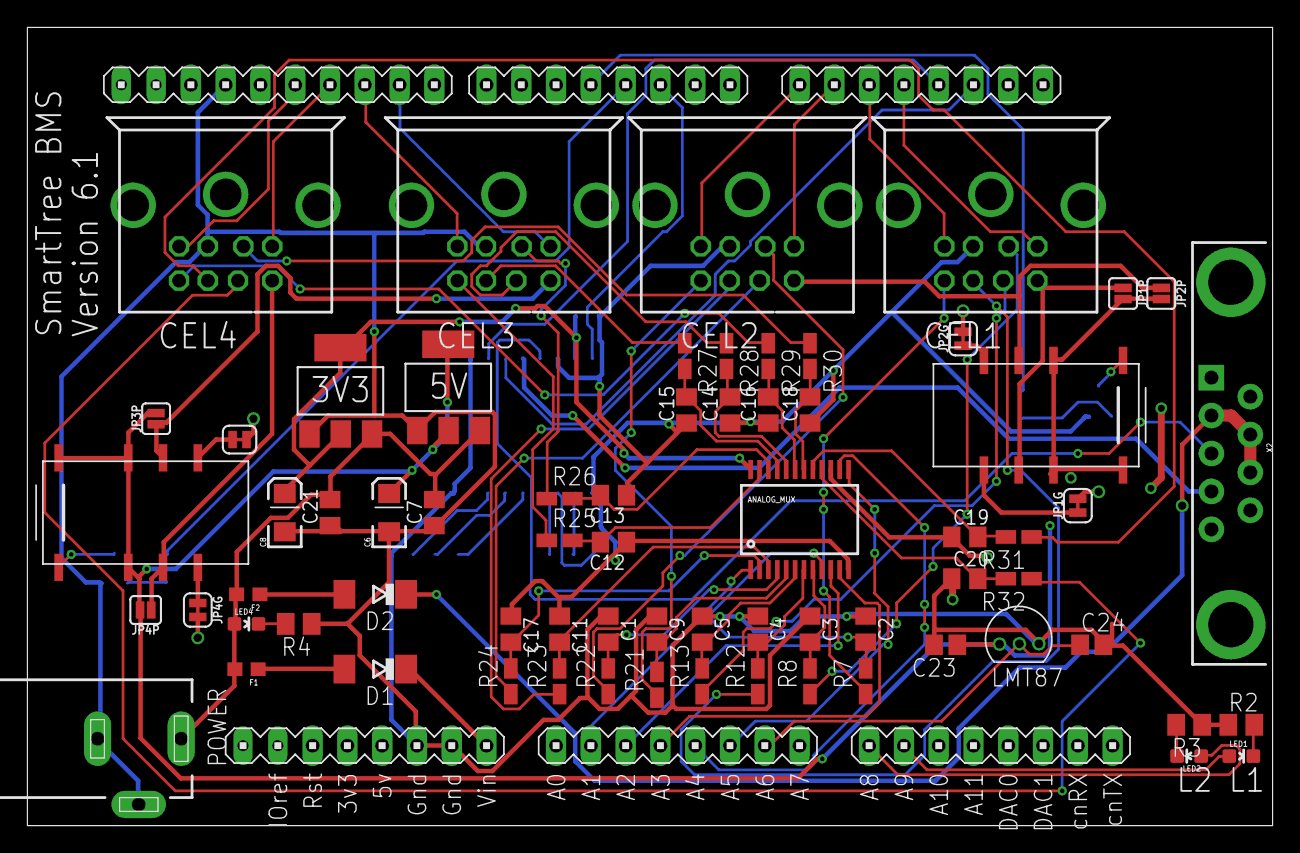
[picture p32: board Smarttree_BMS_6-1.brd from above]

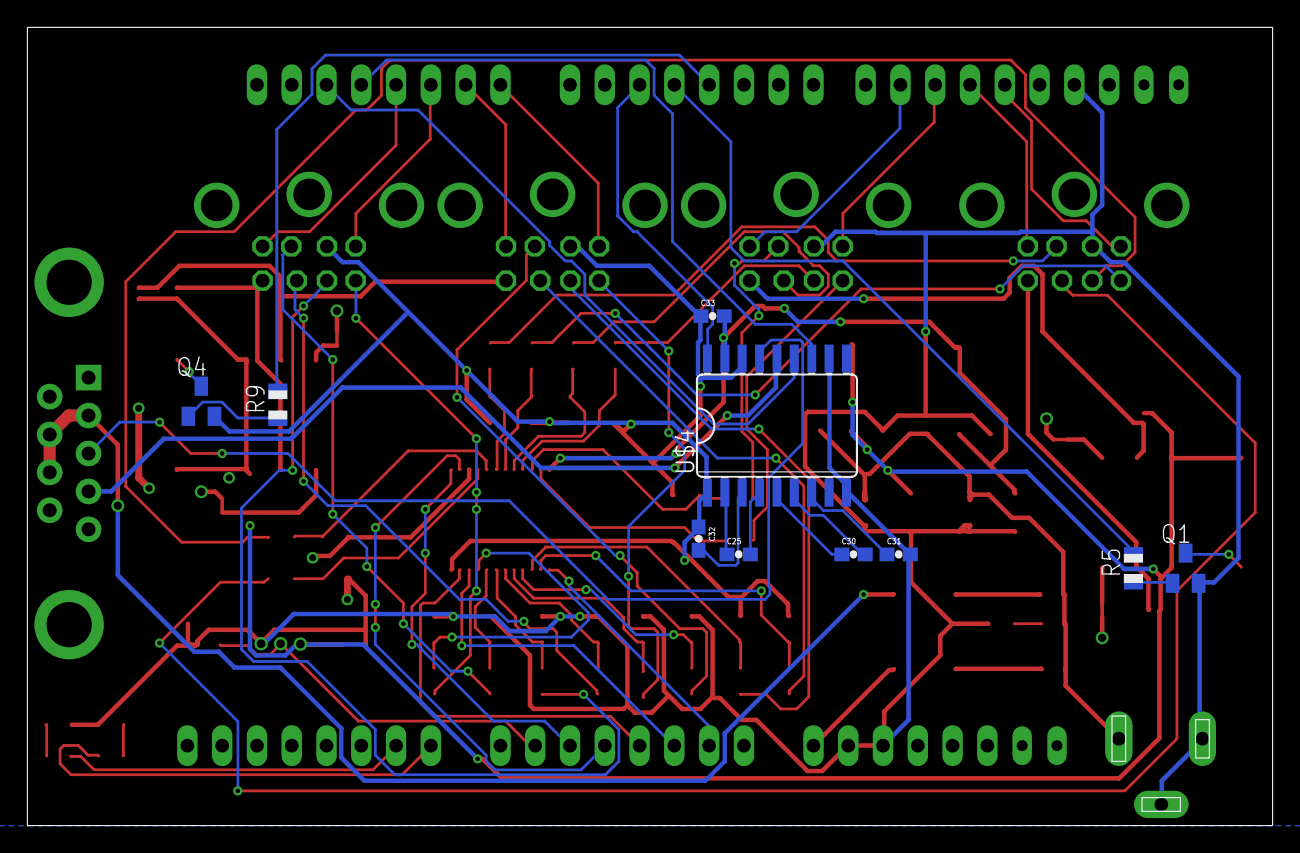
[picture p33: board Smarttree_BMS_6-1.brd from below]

Board: 2 copper layers, 90.9 x 58.3 mm, 79 parts (10 on the bottom side), 84 nets.

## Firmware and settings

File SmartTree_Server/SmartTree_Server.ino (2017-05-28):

// latest version
#include <SPI.h>

// rtc include 
#include <rtc_clock.h>

// due flash storage 
#include <DueFlashStorage.h>
#include <efc.h>
#include <flash_efc.h>
#include <math.h>

// external library for interrupt 
#include <DueTimer.h>

// library we wrote 
#include "constants.h"
#include "bmucell.h"
#include "util.h"
#include "update.h"
#include "error.h"
#include "transmitter.h"
//#include "debug.h"


#define NUM_CELL 1

volatile Cell cells[] = {
  Cell(0), Cell(1), Cell(2), Cell(3)
};



DueFlashStorage dueFlashStorage; // Due own flash storage for the energy bar
RTC_clock rtc_clock(XTAL);       // Due internal RTC for counting date



// global variables for the sensor value (voltage is the average, currentIn, currentOut are sums)
double g_voltage = 0;
double g_currentIn = 0;
double g_currentOut = 0;


 
byte preventRefresh = 0; // flag to prevent refreshing in the case of an error 
byte mode = 0;                   // state machine (normal, error, sleep, debug) // sleep and debug not implemented. 


volatile bool logDataFlag = false;
volatile bool updateScreenFlag = false; // volatile variables for trigger interrupt 
volatile byte logDataCurrentCell = 0;

void setup() {
  Serial.begin(115200);   // serial debug interface
  Serial1.begin(9600); // RS232 Screen communication interface
  
  // initScreen();        // initialize screen
  initRTC(16,40,0,1,5,2017); // hh/mm/ss dd/mm/yr
  transmitClearMessage();     // initialize transmitter (reload screen background)
  
  // init BMS; 
  Cell::setup();       
  
  // TODO set priorities for ints
  Timer.getAvailable().attachInterrupt(setLogDataFlag).start      (1000000); // trasnmit log data to the screen
  Timer.getAvailable().attachInterrupt(setUpdateScreenFlag).start (2000000); // transmit display data to the screen
  Timer.getAvailable().attachInterrupt(globalBatteryCheck).start  (100000);  // BMS check

}

void loop() {
  
  if(IN_NORMAL_MODE_STRICT(mode)) {
  // Serial.println("BMS in Normal Mode");

      digitalWrite(RI1, HIGH); 
      digitalWrite(RO1, HIGH);
      digitalWrite(RI2, HIGH); 
      digitalWrite(RO2, HIGH);

    if (preventRefresh) // if last mode is error, clear preventRefresh flag, refresh screen 
    {
        transmitClearMessage();
        preventRefresh = 0;
    }


    if(updateScreenFlag) { // if timer interrupt is triggered
      updateScreenFlag = false;    
      updateScreen(g_voltage,g_currentIn,g_currentOut);               // update screen value 
      updateScreenUponDateChange(); // update energy bars
    }

  } else if(IN_ERROR_MODE_STRICT(mode)) {

    if(!displayError(cells, NUM_CELL) && updateScreenFlag) { // display error once (displayError is the error handling function) 
      updateScreenFlag = false;
      updateScreen(g_voltage,g_currentIn,g_currentOut);  
      updateScreenUponDateChange();
    }
    else if(updateScreenFlag)
    {
      updateScreenFlag = false;
      updateScreen(g_voltage,g_currentIn,g_currentOut);  
      updateScreenUponDateChange();
    }

  } else if(IN_SLEEP_MODE_STRICT(mode)) {
    transmitMessage(SLEEP);
  } else if(IN_DEBUG_MODE_STRICT(mode)) {
    // start or continue debug interface
  }

  if(logDataFlag) { // if log data timer interrupt is triggered 
  
  // serial debug
    logDataFlag = false;
    // printDate(Serial);                         // print out date
    // Serial.println();
    // printTime(Serial);                         // print out time
    // Serial.println();

    cells[logDataCurrentCell].logData(Serial); // print out cell data

    if(IS_FLAG_SET(mode, ERROR_FLAG)) {        // print out error
      cells[logDataCurrentCell].logErrors(Serial);
    }
    
    // actual transmission
    transmitLogData(logDataCurrentCell, cells[logDataCurrentCell].getVoltage(), cells[logDataCurrentCell].getCurrentIn(),
                cells[logDataCurrentCell].getCurrentOut(), cells[logDataCurrentCell].getTemperature(),
                cells[logDataCurrentCell].getErrorFlags());
    // transmit to the screen
  }
  
}

// BMS check interrupt
void globalBatteryCheck() {
  

  bool allCellsNormal = true;
  g_voltage    = 0;
  g_currentIn  = 0;
  g_currentOut = 0;

  for(int i = 0; i < NUM_CELL; i++) {
    cells[i].update(); // read in new sensor for all of them

    if(cells[i].checkErrors()) { // check errors
      allCellsNormal = false; 
      SET_FLAG(mode, ERROR_FLAG);
    }
    
    g_voltage    += cells[i].getVoltage();
    g_currentIn  += cells[i].getCurrentIn();
    g_currentOut += cells[i].getCurrentOut();
  }
  
    // cells[NUM_CELL-1].update(); // read in new sensor for all of them

    // if(cells[NUM_CELL-1].checkErrors()) { // check errors
    //   allCellsNormal = false; 
    //   SET_FLAG(mode, ERROR_FLAG);
    // }
    
    // g_voltage    += cells[NUM_CELL-1].getVoltage();
    // g_currentIn  += cells[NUM_CELL-1].getCurrentIn();
    // g_currentOut += cells[NUM_CELL-1].getCurrentOut();


  if(allCellsNormal) {
    CLEAR_FLAG(mode, ERROR_FLAG);
  }

  g_voltage = g_voltage / NUM_CELL;
}


void setUpdateScreenFlag() {
  updateScreenFlag = true;
}

void setLogDataFlag() {
  if(logDataFlag) 
    return;
  logDataFlag = true;
  logDataCurrentCell++;
  Serial.println(" log data ");
  if(logDataCurrentCell == NUM_CELL) {
    logDataCurrentCell = 0;
  }
  
}

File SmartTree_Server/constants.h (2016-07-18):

#ifndef CONSTANTS_H
#define CONSTANTS_H

#define LOG_FILE_NAME "Jan 2nd Noon.csv"

#define DEBUG_PIN A0

#define ON_BOARD_TEMP A6

#define LED1 A8
#define LED2 A9

// ADC controls
#define ADDR0 A2
#define ADDR1 A3
#define ADDR2 A4
#define ADDR3 A5
#define ADCPIN A1

// Relay outputs
#define RI1 16
#define RO1 17
#define RI2 14
#define RO2 15
#define RI3 10
#define RO3 9
#define RI4 12
#define RO4 11
#define RSCREEN 3

#define SD_CHIP_SELECT  53

#define DEBUG_FLAG 0b100
#define SLEEP_FLAG 0b010
#define ERROR_FLAG 0b001

#define IS_FLAG_SET(FIELD, FLAG) (((FIELD) & (FLAG)) != 0)
#define IS_FLAG_CLEAR(FIELD, FLAG) (((FIELD) & (FLAG)) == 0)
#define SET_FLAG(FIELD, FLAG) FIELD |= (FLAG);
#define CLEAR_FLAG(FIELD, FLAG) FIELD &= ~(FLAG);

#define IN_NORMAL_MODE_STRICT(FIELD) (((FIELD) & 0b111) == 0b000)
#define IN_ERROR_MODE_STRICT(FIELD) (((FIELD) & 0b111) == 0b001)
#define IN_SLEEP_MODE_STRICT(FIELD) (((FIELD) & 0b110) == 0b010)
#define IN_DEBUG_MODE_STRICT(FIELD) (((FIELD) & 0b100) == 0b100)
#endif

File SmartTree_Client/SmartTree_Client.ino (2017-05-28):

#include <SPI.h>
#include <SdFat.h>
#include <UTFT.h>
#include <UTFT_SdRaw.h>
#include <DueTimer.h>
#include "receiver.h"
#include "tft.h"
#include "log.h"
#include <stream.h>[p]
#include <string.h>
#include <stdlib.h>

SdFat sd;
SdFile file;
UTFT GLCD(CTE70, 25, 26, 27, 28);
UTFT_SdRaw files(&GLCD);

Receiver r(Serial1, "BCDEeLMNnRSW"/*these are the valid commands*/);

unsigned int energyBars[8] = {0};
unsigned int energyBarLength = 1;
unsigned int batteryMeter = 0;
int powerIn, oldEnergy, powerOut, totalEnergy;

bool isCardPresent = false;
char fname440[] = "smarttree.raw";
char *logFileNames[4] = { "Cell_0.csv", "Cell_1.csv", "Cell_2.csv", "Cell_3.csv" };

volatile int hb = 0;
volatile int hb_prev = 0;


// TODO write function to write headers for log files if log files are not present
void setup() {
  Serial.begin(19200);
  Serial1.begin(9600);
  Serial.setTimeout(2000);
//  SDInit();
  initSD();
  initLCD();
// watchdog timer to be 4.5 secs
  uint32_t wdp_ms = 1152 ;
  WDT_Enable( WDT, 0x2000 | wdp_ms | ( wdp_ms << 16 ));
//
  pinMode(9, OUTPUT);   //  screen on /off pin
  digitalWrite(9, HIGH);

  pinMode(14, OUTPUT);  //  shutdown pin
  digitalWrite(14, HIGH);
  r.reply(REPLY_READY);
}

void loop() {
  WDT_Restart(WDT);
   Serial.println("Start receiving message");
//  watchdogReset();

  if (r.receiveData()) {
    Serial.println("Get some data") ;
    r.reply(REPLY_SUCCESS);
    r.reply(REPLY_BUSY);
    execute();
    r.reply(REPLY_READY);
  }
  else {
    r.reply(REPLY_FAILED);
  }
}


void execute() {
  switch(r.type()) {
    case 'B': // draw energy bar
      energyBarLength = min(r.size(), 8);
      for(int i = 0; i < energyBarLength; i++) {
        energyBars[i] = atoi(r[i]);
      }
      updateEnergyBars(energyBars, energyBarLength);
      break;
    case 'C': // clear notice msg area
      GLCD.clrScr();
      files.load(0, 0, 800, 480, "sc.RAW", 1);
      Serial.println(F("LCD Initialised."));
      break;
    case 'D': // draw normal screen data
      if(r.size() != 4) break;
      powerIn = atoi(r[0]);
      oldEnergy = atoi(r[1]);
      powerOut = atoi(r[2]);
      totalEnergy = atoi(r[3]);
      updateScreenValues(powerIn, oldEnergy, powerOut,totalEnergy);
      break;

    case 'E': // draw error box and msg
      drawErrorBox();
      for(int i = 0; i < r.size(); i++) { // print out error message
         char* temp = new char [strlen(r[i])];
         strcpy(temp, r[i]);
         int len = strlen(temp);
         temp[len-1] = ' '; //(null terminating string produce random characters (already handled on the UTFT side)
         GLCD.print(temp, 120, 120 + 32 * i);
      }
      break;
    case 'L':
      if(r.size() != 2) break;
      logToFile(atoi(r[0]), r[1]);
      break;
    case 'M': // draw battery meter
      if(r.size() != 1) break;
      batteryMeter = atoi(r[0]);
      updateBattery(batteryMeter);
      break;
    case 'N': // draw notice message
      setupPrintMinorError();
      for(int i = 0; i < r.size(); i++) {
         char* temp = new char [strlen(r[i])];
         strcpy(temp, r[i]);
         int len = strlen(temp);
         temp[len-1] = ' '; //(null terminating string produce random characters (already handled on the UTFT side)
         GLCD.print(r[i], 570, 200 + 20 * i);
      }
      break;
    case 'R': // refresh normal screen
      files.load(0, 0, 800, 480, fname440, 1);
      updateScreenValues(powerIn, oldEnergy, powerOut, totalEnergy);
      updateEnergyBars(energyBars, energyBarLength);
      updateBattery(batteryMeter);
      break;
    case 'S': // sleep
      digitalWrite(9, LOW); // chip enable pin
      break;
    case 'W': // wake
      digitalWrite(9, HIGH);
      break;
  }
}

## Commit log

2016-07-20 fix receiver serial1.begin location and add debug message
    [SmartTree_Client.ino, SmartTree_Server.ino, bmucell.cpp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]
2016-07-29 Screen communication fix: rogue pointer and resolve energy update location
    [SmartTree_Client.ino, SmartTree_Server.ino, TFT.cpp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]
2016-08-03 add pcb
    [Smarttree_CMU_5.2.3.brd, Smarttree_CMU_5.2.3.sch]
2016-08-10 error message clean up and handling
    [SmartTree_Client.ino, bmucell.h]
2017-01-16 CMU board
    Add cmu board to the documentation
    [Smarttree_BMS_3.1.brd, Smarttree_BMS_3.1.sch]
2017-03-06 comments about changes
    [Smarttree_CMU_5.2.3.brd, Smarttree_CMU_5.2.3.sch]
2017-03-06 bms cnt'd
    [Smarttree_CMU_5.2.3.brd, Smarttree_CMU_5.2.3.sch]
2017-03-29 add new pcb
    [Smarttree_BMS_3.2.brd, Smarttree_BMS_3.2.sch]
2017-03-29 replace old CMU board
    [Smarttree_CMU_5.2.3.brd, Smarttree_CMU_5.2.3.sch]
2017-04-02 test current sensor and relay
2017-04-05 new cmu pcb
    [Smarttree_BMS_3.2.brd]
2017-04-08 gerber file and finalized cmu design
    [Smarttree_BMS_3.2.brd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]
2017-04-19 BMS with the new connectors
    [Smarttree_CMU_6.brd, Smarttree_CMU_6.sch]
2017-04-20 rm old cmu;
    [Smarttree_CMU_6.brd, Smarttree_CMU_6.sch]
2017-04-20 rename and arrange files
    [Smarttree_BMS_3.1.brd, Smarttree_BMS_3.1.sch, Smarttree_BMS_6.brd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]
2017-04-20 new connector on cmu
    [Smarttree_CMU_4.brd, Smarttree_CMU_4.sch]
2017-04-24 comp holes
2017-04-24 modified bms threshold
2017-04-26 bms final
    [Smarttree_BMS_6.brd, Smarttree_BMS_6.sch]
2017-04-26 order files
    [Smarttree_BMS_6.brd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]
2017-04-26 gerber cmu with new connector footprint
    [Smarttree_CMU_4.GBL, Smarttree_CMU_4.GBO, Smarttree_CMU_4.GBP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]
2017-04-27 clean up cmu folder
    [Smarttree_BMS_3.1.brd, Smarttree_BMS_3.1.sch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]
2017-05-02 finalized bms
2017-05-08 aesthetik fixes
    [Smarttree_BMS_6.brd, Smarttree_BMS_6.sch]
2017-05-08 cleanup #b and #s and Gerber files
    [Smarttree_BMS_6.GBL, Smarttree_BMS_6.GBO, Smarttree_BMS_6.GBS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]
2017-05-08 new gerber
    [Smarttree_BMS_6-1.GBL, Smarttree_BMS_6-1.GBO, Smarttree_BMS_6-1.GBP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]
2017-05-10 revise resistor value for current sensor
    [Smarttree_CMU_4.GBL, Smarttree_CMU_4.GBO, Smarttree_CMU_4.GBP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]

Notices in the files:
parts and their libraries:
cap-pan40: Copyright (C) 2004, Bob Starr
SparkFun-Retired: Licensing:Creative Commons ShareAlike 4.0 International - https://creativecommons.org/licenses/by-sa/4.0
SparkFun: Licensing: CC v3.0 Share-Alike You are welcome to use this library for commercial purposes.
